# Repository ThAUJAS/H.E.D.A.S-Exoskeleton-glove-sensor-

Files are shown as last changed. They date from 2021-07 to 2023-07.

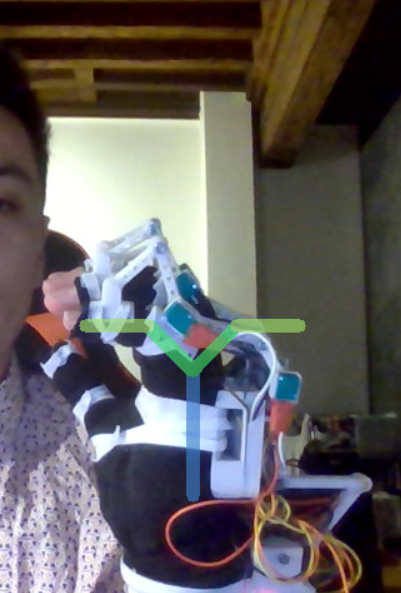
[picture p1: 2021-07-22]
image/45_finger.png

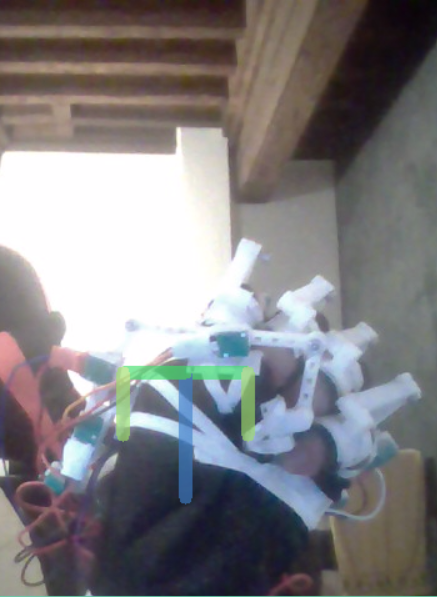
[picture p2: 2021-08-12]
image/90_thumb.png

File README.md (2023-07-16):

# H.E.D.A.S The Exoskeleton glove sensor
This repo is the result of my master thesis for the Staffordshire University. The idea was to create a glove capable of measuring accurately the finger movements (almost every DOF) using cheap sensors (potentiometers). The structure of the glove is fully in 3D parts and assembled with some screws and bolts. The circuit is simple, yet very messy since we have a ton of potentiometers. The values are collected by an Arduino Nano and a multiplexer. Then, I used Unity to simulate a virtual hand, and see if the movements of my hand and the virtual one were corresponsing. 

**The repo is open source, you can Fork and modify as you wish my codes and my design.**

## How to use it
Launch the python script "HEDAS_code" to start the program. A window will open and you will:
- select the port to which the arudino is connected.
- choose whether you want to do another calibration or use a saved one.

The calibration is performed in 5 steps which requires different hand and fingers positions. You can choose to display the camera to help you calibrate. Then, save the calibration under a unique name.

## Requirements
- Tkinter (For the window display)
```
pip install tk
```
- OpenCV (Optional(webcam help for calibration))
```
pip3 install opencv-python
```

## What's included
They are a bunch of files here:
- **HEDAS_code.py** is the Python script. 
- **H.E.D.A.S.ino** is the Arduino code, just compile the file in the Arduino.
- *Sample.json* is the file where the calibrations are saved.

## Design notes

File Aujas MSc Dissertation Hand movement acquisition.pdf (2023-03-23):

ELEC71020 – MSc Project

## Development of a low cost and easy to assemble glove for hand movement acquisition as an open-source project

By Thomas AUJAS

Supervised by Dr Alison Griffiths

A thesis submitted to the Faculty of Computing, Engineering and Science, Staffordshire

University in fulfilment of the requirement for the MSc Robotics and Smart Technologies

MSc Robotics and Smart Technologies

20th of August 2021

School of Creative Arts and Engineering

Staffordshire University

Student number: 20015669

a015669k@student.staffs.ac.uk

## Abstract

Over the past few years, Virtual Reality (VR) has managed to accurately replicate the reality to

immerse the user in a simulated world. One of VR’s best aspect is the interaction with the

environment like grabbing or touching virtual objects. Moreover, many companies developed

gloves to be able to sense hand movements and reproduce them in game for even better

immersion. Therefore, the gloves can be also used for mining, military, transports, and

construction simulators. Sensor gloves are useful in other domains such as medicine. Indeed,

the sensor gloves can be used to measure finger joint angles to control Arthritis (a disabling and

painful disease) easily and with precision. It is also used to control an anthropomorphic robotic

hand and exo-gloves (for rehabilitation purposes) that mimics movements. It could benefit a

wide range of research areas such as in robotics using telemanipulation, or in the medical field

(tissue engineering) for limb regeneration. Finally, it can be used to translate sign language into

a speech or text. The requirements change depending on the application of course, for VR

mainstream games, the accuracy and the number of joints measured by the gloves is low. For

simulations, medicine, accuracy is really important as well as measuring as many joint as

possible. Of course, cost changes depending on the application, whereas for VR games, the cost

must be accessible to the general public, in medicine, the equipment is expensive. Developing

an accessible cost glove while accurately measuring all the hand joints is the goal of the project.

To do so, a 3D printer is involved to print all the necessary parts of the glove. The glove is also

composed of potentiometers that measures the angles. The angles are obtained in different

ways, with a linear relationship or with a second-degree relationship, which requires a

calibration. The calibration helps to have referential position and values, as well as estimating

the polynomial relation between the potentiometers and the joints’ angles. Some testing has

been performed to determine the accuracy and repeatability. The results were acceptable with

a good accuracy overall, but a bad repeatability. The latter could be improved by attaching the

device better to the hand. Another test included a game design software to simulate a hand

model (Unity) was also performed. The hand model moved accordingly to the angles from the

glove values. From the user point of view, the hand is synchronised with its hand, which is

already convenient for VR games.

## Table des matières

4.2 | Arduino code | 37
4.3 | Python | 38
4.3.1 | Receiving the data while interfacing | 38
4.3.2 | Calibration | 40
4.3.3 | Saving the calibration with JSON | 45
4.3.4 | Processing the data | 47
4.4 | Summary | 48
Testing the glove | 49
5.1 | Testing with Unity for a fast visual verification | 49
5.1.1 | Communicating with Python | 49
5.1.2 | Moving the virtual hand | 49
5.1.3 | Visual feedback | 51
5.1.4 | DIP joint issues | 51
5.2 | Accuracy test (and precision test) | 52
5.2.1 | Visual test with an overlay for MCPx, PIP and wristx | 52
5.2.2 | Comparison with an IMU | 53
5.2.3 | MCPz accuracy | 54
5.3 | Repeatability | 55
5.4 | Testing the device on participant’s hand | 56
5.5 | Response time | 56
5.6 | Summary | 56
Conclusion | 57
6.1 | Comparison to objectives | 57
6.2 | Critical appraisal | 57
6.2.1 | Performance | 57
6.2.2 | Calibration | 57
6.2.3 | Electrical components | 58
6.3 | Future work | 58
6.3.1 | Adding the second hand | 58
6.3.2 | Adding a wireless communication | 58
6.3.3 | Adding a haptic feedback | 58
6.3.4 | PCB (Printed circuit board) | 58
References | 59
Appendices | 62
A. GitHub link | 62
B. Unity program | 62

## List of figures

Figure 1: Price range market research results | 9
Figure 2: Spectra Symbol flex sensor 3.75 inches | 10
Figure 3: IMU GY-521 [6] | 11

Figure 5: Flex sensor glove: a) for VR [9], b) for robot hand with additional sensor for the

Figure 6: Rotary sensor glove [11]: a) Kinematics diagram, b) Final design by Ivan Petrov.. 12

Figure 10: Very similar design using IMUs: a) IGES glove [14], b) Salchow-Hömmen’s IMU

Figure 36: Tkinter window, for Hand flat, finger close and thumb far away | 42
Figure 37: Tkinter window, for Hand halfway closed | 43
Figure 38: Tkinter window, for Hand closed | 43
Figure 39: Tkinter window, for Wrist folds at-45° | 44
Figure 40: Tkinter window, for Wrist folds at 45° | 44
Figure 41: Plot of the regression using the Python polyfit function | 45
Figure 42: Tkinter window, asking for the name of the calibration | 46
Figure 43: JSON file storing all the data of calibration | 46
Figure 44: Initial position in simulation | 50
Figure 45: Testing different hand pose in Unity without using the wrist | 51
Figure 46: Test with the overlay at 30° and 60° for both joints | 52
Figure 47: Accuracy test with an IMU connected to a Raspberry Pi | 53
Figure 48: Comparison of measurements of the MPCx from the device and the IMU | 54

Figure 49: MPCz test with major and Index closed, then separated using a 20° 3D printed

spacer | 55
Figure 50: Repeatability test on MCPx | 55

## List of Tables

Table 1: Enumeration of the Degrees Of Freedom of the hand and fingers | 19
Table 2: “Potentiometer” angles collected from the Finger joint angles | 23
Table 3: Glove 3D parts explanations | 28
Table 4: Bill of material for one glove | 36
Table 5: Final organisation of the glove data | 48

## List of Acronyms

Acronym | Meaning | Definition
CAD | Computer Aided Design | Set of software and geometric modelling techniques to design, test virtually - using a computer and digital simulation techniques - and produce manufactured products and the tools to manufacture them.
CMC | Carpometacarpal | Joint where the metacarpal bone of the thumb attaches to the trapezium (carpal) bone of the wrist

DIP | Distal interphalangeal | Joint situated between the proximal bones and the distal phalanges (https://en.wikipedia.org/wiki/Phalanges) of the fingers
DOF | Degrees Of Freedom | The Degrees Of Freedom of a rigid body is defined as the number of independent movements it has.
IMU | Inertial Measurement Unit | Sensor used in navigation, capable of integrating the movements (acceleration and angular speed) to estimate the orientation (roll, pitch and heading angles), its linear speed and its position.
MCP | Metacarpophalangeal | Joint situated between the metacarpal (https://en.wikipedia.org/wiki/Metacarpal) bones and the proximal phalanges (https://en.wikipedia.org/wiki/Phalanges) of the fingers
PCB | Printed Circuit Board | is a support, making it possible to maintain and electrically connect a set of electronic components to one another
PIP | Proximal interphalangeal | Joint situated between the intermediate bones and the proximal phalanges (https://en.wikipedia.org/wiki/Phalanges) of the fingers
VR | Virtual Reality | Computer technology that simulates the physical presence of a user in an environment artificially generated by software

## Introduction

1.1 Aim

Sensor gloves for hand and finger movements acquisition are often very expensive due to the

difficulty required to sense the fingers joints. The price depends on the field in which the glove

will be used. For instance, the gloves used in mainstream Virtual Reality (VR) games only

measure “how much the finger have bent” since accuracy is not their aim, but the time response

is. However, in the field of medicine, all the joints must be measured with accuracy and

precision.

The aim of the project is to develop one sensor glove able to measure the all the angle of the

fingers’ joints with accuracy and precision. It has to be low-cost and accessible for the general

public to be assembled at home requiring only a 3D printer (an open-source project).

1.2 Objectives

- Using Microsoft Forms, writing a questionnaire to start a market research on the project

area. The market research will define what people want/need and in which domain the

glove will contribute the most.

- Literature reviewing some article describing the sensors and the methods to measure the

human hand movements.

- Inspired by the many articles, designing the system with a suitable implementation. Of

course, before testing the whole device, intermediate design ideas must be tested; one

finger, then the thumb and so on.

- Assembling and programming the device, an accuracy and a repeatability test will be

performed.

- Displaying a user interface to simplify the connection and the calibration process.
- Finishing the dissertation with the suggestions for improvements based on the test and

the market research.

- Creating GitHub project to have a link to share the codes (and printing files).
- Writing the dissertation document and preparing the oral presentation.

1.3 Justification of hand acquisition system implementation

Using the results of the market research, a justification for the glove be found. The market

research was a form with multiple question about interest potential users have in this artifact

and why. First, a question asking what such a glove could be used for. The most common

answers were:

- In the industry to manipulate hazardous or contaminated materials.
- For Virtual reality (VR) games or VR training simulation for dangerous operations.
- Replace game controllers and keyboards.
- Rehabilitation of the hand.
- Controlling a surgical robot at distance.
- Motion capture for the film or animation industry.

Nowadays, this type of glove is mostly known to be used for VR games, for motion capture and

for hand rehabilitation [1]-[2]. However, nobody mentioned the use of the sensor glove for a

sign language training system [3]. To know the interest of people in this technology, the

following questions were about the interest in buying a sensor glove. 71 people answered the

questionnaire, 40 would like to buy one. Next, independently from the previous answer, the

question was: “What price ranges would you be willing to pay in pounds? Or which price seems

reasonable?”. The graph bellow shows the result of the question. The chosen ranges are

between 20 to 500 pounds with a peak for 50-100, and there are very few people that are willing

to pay over 500 pounds.

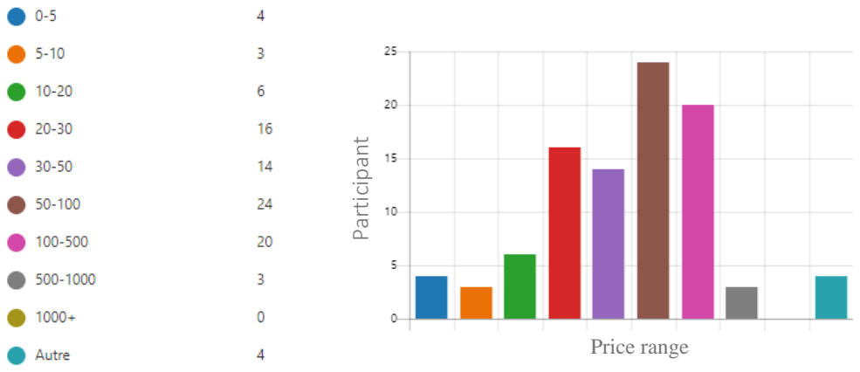
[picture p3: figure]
Price range; Participant

Figure 1: Price range market research results

Concerning the last question, it was asked to give a justification about the price ranges choice.

Most people said that it all depends on the quality of the product (accuracy, speed, precision,

material) and the use of it. For instance, for a domestic use (VR games) a small price is

sufficient, but for a medical use, the price should be higher since the quality should be better.

Many other said that they will not have any personal use for such a glove, which implies that

they do not want to spend too much.

Lastly, since the project is open source, knowing if someone is willing to build the glove is

important. In the questionnaire, it is asked if they had a 3D printer and there is only four people has one at home. Then, the same people were asked if they were interested in printing, buying

the electrical components, and assembling the glove. To this question, three said that they would

try this project.

From the answers given in the market research, it seems that people have an idea of what this

device is capable of. However, less than the half is not interested because they do not see a

personal use. Finally, very few people own a 3D printer and only young people that sees the

potential in VR games are interested in the project. Indeed, the project promises something

inexpensive compared to what in proposed currently, and as seen in the result for the price

ranges, from 100-500 pounds it starts to be expensive.

1.4 Dissertation organisation

The first step for any project to search which sensor suits the most the project. Therefore, the

first section will be about the many glove sensor articles which will be analysed to conclude on

which sensor is appropriate for the project. Then, the dissertation will continue with the design

choices and the system implementation. Next, the glove will be subject to multiple tests and the

results will be discussed in this part. Finally, the dissertation will reach the conclusion, where

a critical appraisal and further works will be discussed.

## Literature review: Methods for hand movement acquisition

2.1 Sensors usually used for hand movement data acquisition

2.1.1 Flex sensor:

The flex sensor is composed of a flexible conductive ink printed on thin flexible base forming

a resistor. The work principle of those sensors is similar to a potentiometer: when they are

folded, their resistances change. The value of the resistance corresponds to “how much the

sensor has been bent”. The unit price for this sensor is between £8-15 [4]-[5] (Figure 1), which

is the highest cost sensor of all.

Figure 2: Spectra Symbol flex sensor 3.75 inches

2.1.2 IMU (Inertial Measurement Unit) (https://www.microstrain.com/inertial/IMU): (https://www.microstrain.com/inertial/IMU)

This sensor measures a body's specific force and angular rate. Therefore, they are composed of

6-axes: a 3-axis accelerometer and 3-axis gyroscope (sometimes 9-axis with a magnetometer).

To build a glove sensor, the values of accelerometer (for orientation) as well as the gyroscope

(for angular speed) are required. The unit price of the IMU is around £0.5 [6] (Figure 3).

Figure 3: IMU GY-521 [6]

2.1.3 Potentiometers

Potentiometers are a three-t (https://en.wikipedia.org/wiki/Terminal_(electronics))erminal (https://en.wikipedia.org/wiki/Terminal_(electronics)) r (https://en.wikipedia.org/wiki/Resistor)esistor (https://en.wikipedia.org/wiki/Resistor) with a sliding or rotating contact that forms an

adjustable voltage divider. Both slider and rotational potentiometer can be used to measure the

joint angles, however, they are used in different ways. For the rotary sensor, the shaft rotates in

the body of the potentiometer, whereas for the slider, the shaft slides inside the body. They are

the cheapest sensor, often sold by group of 10 for less than £3 [7]-[8] (Figure 4).

a | b

Figure 4: Potentiometers a) Rotary [7], b) Slider [8]

2.2 The designs, sensor placement and data acquisition

2.2.1 Virtual Reality acquisition system

The flex sensor is widely known for this type of glove, the sensors were used in the first glove

sensor created for video games: The Power Glove by Nintendo. Therefore, the design is similar

with the sensors glued or stitched to a stretchable glove at each finger from the start to the end

of the finger (Figure 5).

a | b

Figure 5: Flex sensor glove: a) for VR [9], b) for robot hand with additional sensor for the wrist [10]

This type of glove is most likely used for VR because it uses only 5 flex sensors which only

measure how much the fingers have been bent. The rotary potentiometer can also be used to

control the bent angle as well, by 3D printing two links linked by a revolute joint [11] (Figure

6) with:
- the first link fixed to the potentiometer’s shaft and the potentiometer’s body is

embedded to the proximal phalange.

- the second link forms a revolute joint with a part embedded to the distal

phalange.

a | b

Figure 6: Rotary sensor glove [11]: a) Kinematics diagram, b) Final design by Ivan Petrov

2.2.2 Measuring more joints with higher accuracy

Now, if the glove must be used for data analysis with higher accuracy and with more joints

measured, increasing the number of sensors is required. Moreover, they need to be placed in a

different configuration with a specific placement on the hand. For instance, the company 5DT

created the Data Glove ultra 14 in Figure 7 [12] with two sensors for each finger (positioned on

the joints), which allows the glove to measure the joints separately. There are also 4 additional

flex sensors between every finger to detect the fingers movements.

Figure 7: 5DT glove sensor 14 Ultra [12]

Therefore, by applying the same reasoning, adding 2 sensors for each finger to Ivan Petrov’s

glove design improves the number of movements detected by the glove (see Figure 8).

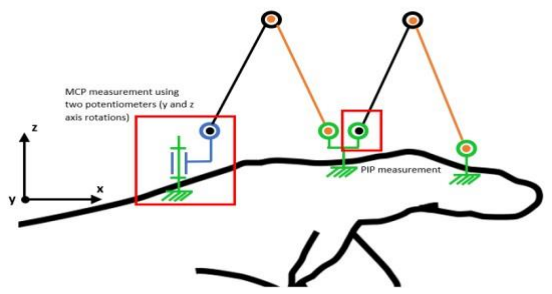
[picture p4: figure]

Figure 8: Modification to Petrov design [11] to measure multiple joints separately

Therefore, by adding more sensor, more joints can be measured, but the glove will be more

expensive of course. Positioning the sensor on the phalanges is the chosen method for the IMU

and the slider potentiometer. An article [13] shows a project that uses slider potentiometers,

springs and flexible wires (fishing lines) to measure only the flexion/extension of the 5 fingers.

The proposed system is showed in Fig. 9 where only one finger is explained for clarity. One

side of the wire is attached to the pole of the slider potentiometer whereas the other end is

attached to the middle of the phalange.

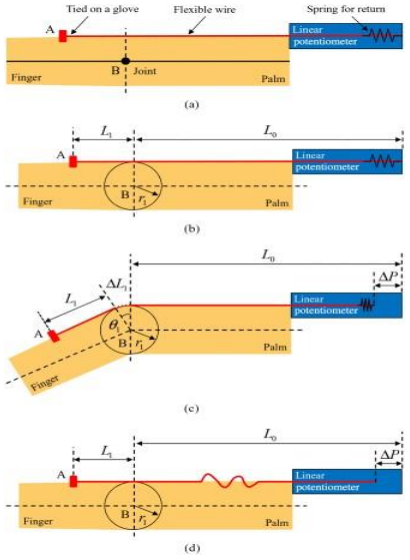
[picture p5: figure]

Figure 9: Slider sensor glove [13]: joint measurement

The angle is computed by measuring the potentiometer value difference which is equivalent to

the value of displacement and knowing the radius of the finger joint which is equal to half the

thickness of the finger, the joint angle is deduced. To compute (or deduce) the angle of the joint,

the sensor displacement of the previous joint must be considered, as the string will pass through

both joints. However, the fingers can move to the right and left but also folding.

Using IMU, measuring all the movement of the joints can be measured more easily. The iSEG-

Glove [14] shown in Fig. 10(a) and the glove developed by Salchow-Hömmen et al [15] in Fig.

10(b) have the same approach: 15 IMUs are positioned on the phalanges of each finger to

measure their orientation and an additional IMU is placed on the palm of the hand to get the

relative orientation and velocity of the phalanges compared to the hand. By measuring the angle

of each IMU and computing the difference in angle between two sensors next to each other, the

orientation of the joints is obtained.

a | b

Figure 10: Very similar design using IMUs: a) IGES glove [14], b) Salchow-Hömmen’s IMU glove [15]

2.3 Data processing

Now that the values are obtained from the sensors, the next step is to process the values. To do

so, a calibration is often used to improve the glove accuracy and define some initial positions.

Furthermore, some sensors require filtering since they are sensitive to noise.

2.3.1 Calibration

A calibration phase must be performed before using the gloves for its purpose. A calibration

routine has been created for every glove to improve the global accuracy of the sensors or simply

make it work properly. The glove wearer must position its fingers in specific poses, with each

pose placing a finger joint group and relevant data glove sensors at their minimum and

maximum boundaries (opened hand and closed hand).

A calibration is necessary if the glove is worn by someone else because the boundaries will be

different. To avoid calibrating every time, a “calibration profile” for each user can be saved.

However, the IMUs require a calibration before usage (by placing the sensor on a levelled

surface) to reduce the errors.

2.3.2 Filtering the noise and signal drift

The data acquired must be treated because many sensors are subject to noise:

- Resistive elements can have signal drift issues.
- IMU’s gyroscope suffers of Angle Random Walk which is a high frequency noise due

to thermoelectrical reactions. Whereas the mechanical noise of the accelerometer sensor comes from thermomechanical noise. Finally, the two IMU’s sensors can have a bias

corresponding to an offset at its output.

By implementing filters before interpreting values, the data can be smoothed and corrected. To

remove the high frequency sensor noise, they must use a low-pass filter, and a high-pass filter

to block low frequency noise. To solve signal drift issues, they removed an estimated error

calculated by getting the average error beforehand.

2.4 Testing methods

Accuracy and Precision (repeatability) tests must be performed to find the performances of the

sensors.

2.5 Accuracy

Measuring the accuracy is difficult because the data from the device must be compared to the

real data. One solution is to compare the sensors between them. The gloves can be compared

with a motion capture device such as the Vicon MX motion. Or the Humanware Humanglove

(UG: Universal Goniometric) with Hall effect sensors, which is one of the most precise glove

sensors for a long time. However, the glove requires a mould of the user’s hand, and it also

requires a tedious amount of calibration. This is the reason this sensor is not consider in the

paper, but it can be used as a reference for testing.

The Salchow-Hömmen et al [15] show the experiment performed in Figure 11: they fixed the

forearm to prevent any disturbance in the motion capture and captured the Vicon and the IMU

glove at the same time. In this experiment, the reference is the motion capture system.

Figure 11: Comparing the IMU and the Vicon system [15]

A similar approach is used for the slider potentiometer [13] in Figure 12. In that case, the IMU

is considered as a reference. The test will consist of folding the fingers multiple times, with the

hand elevated to be able to fold the finger.

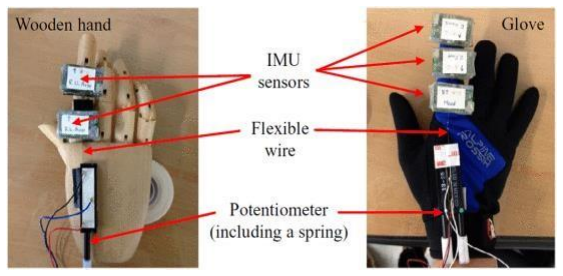
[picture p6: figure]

Figure 12: Testing conditions for slider potentiometers with IMUs [13]

To obtain the best results, the experiment must be performed with multiple devices at the same

time on the same hand. Otherwise, it is really complicated to reproduce the same scenarios or

finger movement for comparison.

2.5.1 Repeatability

Repeatability is the variation in measurements obtained when one person measures the same

unit with the same measuring equipment. For a glove sensor, the values should not shift as the

time goes. Two tests can be performed to control the precision of the glove sensors by [14]:

“The ‘flat hand’ test which examines each data glove’s ability to maintain a minimum

repeatable value after full stretch of each data glove sensor. “and “The ‘plaster mould’ test

examines the ability of each data glove to reproduce angular readings when positioned in a

repeatable position.”.

2.6 Conclusion

To conclude, all the sensors can be used to build a sensor glove, but the goal was to find the

lower cost sensor that can provide an acceptable accuracy and that offers the capability of

measuring all the joints with all their possible movements. The largely used flex sensor is too

expensive to be considered as low cost, exceeding (https://www.linguee.fr/anglais-francais/traduction/exceeding.html) 100£ just for a VR glove whilst being the

easier to implement. The IMU remains the most precise and reliable sensor for any application

(VR or medicine) and the sensors are slightly more expensive than the potentiometers.

Although, it must be calibrated frequently to keep their accuracy and the postprocessing of the

data is more tedious. Finally, the potentiometers are the cheapest sensors, but existing projects

are often protypes and very few tests/ results are provided to conclude on their performances.

Therefore, using potentiometers with Petrov’s method can be the best way to find an

inexpensive solution to complete the objectives and discover the results. Some part of the design

can be similar, though, the calibration and the post-processing should be entirely modified to

fit the aim and the objectives.

## Hand Movement Acquisition: Design and System Implementation

After choosing the potentiometer to measure the hand and finger movements, the design of the

glove will be found. The glove will be composed of many 3D parts develop in a Computer

Aided printed (CAD) software. The part will then be 3D printed and tested. To test, an adequate

program will be developed, as well as the circuitry. Finally, a bill of material containing all the

necessary component to assemble the glove will be established to get the cost of the project.

3.1 Design considerations and technical specifications

The goal is to measure angles the finger joint angle with the lowest cost sensor: the

potentiometers. A potentiometer is a three-t (https://en.wikipedia.org/wiki/Terminal_(electronics))erminal (https://en.wikipedia.org/wiki/Terminal_(electronics)) r (https://en.wikipedia.org/wiki/Resistor)esistor (https://en.wikipedia.org/wiki/Resistor) with a rotating contact that forms

an adjustable voltage divider. The potentiometer’s shaft can rotate around itself in the

potentiometer’s body, therefore, the potentiometer has only one Degree of Freedom. The

Degrees of freedom (DOF) of a rigid body is defined as the number of independent movements

it has.

Each finger has 3 phalanges: proximal, intermediate and the distal phalanx which move with

two joints called proximal inter phalange (PIP) and distal inter phalange (DIP). However,

moving the finger individually is more complex as they move with a freer joint from the hand

called the metacarpal phalange (MCP). The thumb has an additional bone, the Trapezium,

which allows it to move more freely than the others, the joints is called the carpometacarpal

(CMC) joint. The DIP and the PIP are the only joints with one degree of freedom, whereas the

MPC and the CMC have more than one DOF (MPC has 2 DOF and CMC has 3 DOF). All the

joints and phalanges are represented in Figure 13.

Figure 13: Joints and phalanges of the hand

Due to the small area that represents the hand and the fingers, measuring accurately the hand

movement becomes a real challenge. And unfortunately, that makes the devices often very

expensive for the general public. The potentiometers can measure only one degree of freedom,

so a clever design to sense movements on multiple axis must be found. There is a potentiometer

for every DOF in the hand:

Table 1: Enumeration of the Degrees Of Freedom of the hand and fingers

The total number of DOF for the fingers is 22, and 25 with the wrist, which is enormous. The

objective would be to reduce the number of potentiometers used to reduce the cost and the

weight of the device to be more comfortable for the user. Hrabia et al [16] conducted an

experiment to find a relationship between the DIP and the PIP. The movement of the distal

phalange is indeed related on the movement of the intermediate because the two are moved by

the same muscle. Therefore, after experimenting and multiple people and by using a normal

distribution to verify the results, they found an approximated equation relating the two joints

for every finger (except the thumb):

∡DIP = 0.88∡PIP for all four fingers (with SD=0.10, R2=0.77)

From this estimation, the DIP is ignored which reduce the number measurements on the four fingers. Another joint where a DOF that can be ignored is the CMC of the thumb. The CMC, with 3 DOF, allows the thumb to perform a wide variety of movements.

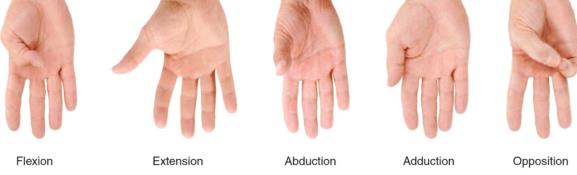
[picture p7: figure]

Figure 14: Movements of the thumb [17]

Joints | DOF Location | Total DOF
DIP | 1 | Every finger | 5*1 = 5
PIP | 1 | Every finger except the thumb | 4*1 = 4
MCP | 2 | Every finger | 5*2 = 10
Wrist | 2 | Only the wrist | 2
CMC | 3 | Only the thumb | 1*3 = 3

This will be the most tricky and difficult joint to measure. Therefore, a relation between the

CMC and MPC of the thumb concerning the abduction and adduction is found. The movement

of the CMC and MPC on the right and left are performed on the z axis, as shown in the Figure

15. The following relationship has been tested in the Part 5.1 of this paper:
∡CMCz | = | 2
3

⁄ ∡MPCz

Finally, concerning the wrist, even though the hand has 3 DOF compared to the arm, the wrist

can be reduced to 2 DOF. Indeed, from the arm the hand can rotate around 3 different axes, but

the wrist offers only 2 rotations. The last rotation is operated by the arm which rotates around

itself. Therefore, this rotation is ignored for our actuation system. Therefore, the total number

of DOF that can be measured is reduced to 19 DOF.

Lastly, the potentiometers are not the smallest (10x11x22 cm) but looking at the size of the

fingers, the size of these potentiometers will not be causing problems. However, it is important

to remind that the aim is to have a comfortable glove for a long use and adaptable to every size

of hand.

Electronically speaking, the Arduino Nano is the microcontroller used to collect the data from

the potentiometers because of its small size. However, as mentioned before, the Arduino must

read 19 potentiometers and there are only 8 analogue pins available on the Arduino. Therefore,

the use of a multiplexer is required, which is an electric component with 16 analogue

inputs/outputs. The multiplexer pins can be read separately by sending a binary number

indicating which pin to read. Finally, the data will be collected by the Arduino and send to the

computer.

3.2 Mechanical design (kinematic diagram)

3.2.1 Kinetic diagram

A kinematic diagram is a drawing of the joints which connect the links together. It is used to

help to understand how a mechanical system moves. Previously in part 3.1, the terminology

“number of DOF” was used, but for the kinematic diagram, it is better to use mechanical joint.

A joint -or mechanical joint- is a section of a machine that connects two a link/part to another,

the name of the joint depends on the number of Degree of Freedom it provides. For instance,

the potentiometer has one DOF, it is therefore called considered as a Revolute joint. The MPC

and wrist have 2 DOF which represent a Universal joint. The CMC has 3 DOF which

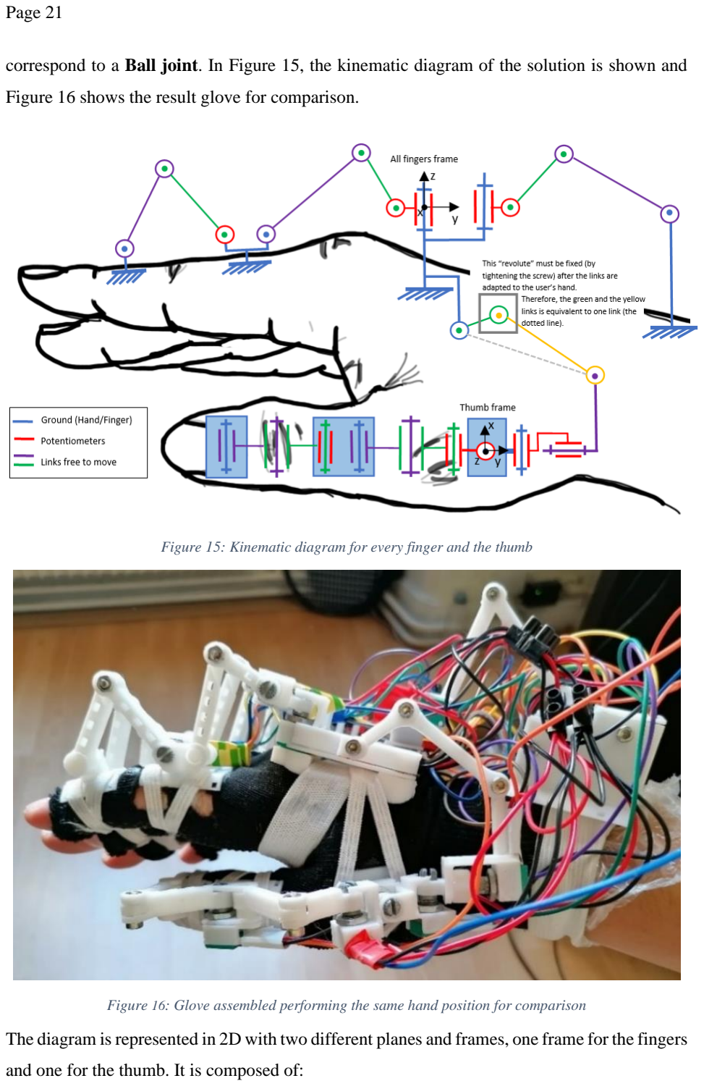
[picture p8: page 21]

correspond to a Ball joint. In Figure 15, the kinematic diagram of the solution is shown and

Figure 16 shows the result glove for comparison.

Figure 15: Kinematic diagram for every finger and the thumb

Figure 16: Glove assembled performing the same hand position for comparison

The diagram is represented in 2D with two different planes and frames, one frame for the fingers

and one for the thumb. It is composed of:

- mechanical joints: In our case, the drawing is exclusively composed of revolute, that

can be represented as a circle or by a cylinder trapped between two lines (because a

revolute joint can only rotate around the axis).

- the body or ground: the ground is the part of a system that does not move, it is fixed.

In our case the grounds are the hand and the fingers (the phalanges in particular).

- links: they are straight lines that link two joints together.

3.2.2 Link movements and angles relations

As stated in the Design considerations, the device’s sensor for the fingers’ joints are

potentiometers which implies that only revolute joints can be utilize. Since the DIP and PIP

joints are revolute, in theory, the measurement of these joint should be easier. In reality, to

measure the angle between two phalanges, the potentiometer’s axis should be situated at the

same location where the finger folds. Unfortunately, this solution is possible only on the side

of the finger, which is only possible for the index and the pinkie. The only location where the

movement of the user will not be contained is on the top of the phalanges. In addition, the glove

must be comfortable and adaptable to every hand size. After testing multiple design and

solutions, a similar design to Ivan Petrov’s work has been found (at least for the joints in the x

axis). Therefore, the final chosen design should have been exploitable. However, in the article,

he measured the bend of the fingers by calibrating a start and end position, whereas the goal of

the project is to measure the finger joints’ angle values. From this design, two types of relation

between the angles of the joints and the sensor values can be found:

- The linear relations: The value obtained by the potentiometer will be the angle at which

the joint moved, which is basically an equality. This happens only when the potentiometer

is the only revolute rotating around an axis. From the Figure 15, only the MCP in the z axis

(reduced to MCPz), the CMC in the x and y axis (reduced to CMCx and CMCy respectively)

and wrist in the z axis (called wristz) are in this case.

- The second-degree relations: to measure the PIP and MCPx, wristx and CMCx which all

rotate around x in their frame, adding a revolute joint was necessary. Indeed, unlike the

MCPz, the when the finger folds, the link will hit the finger. Moreover, the distance between

two phalanges will change as the finger folds.

The final design is two revolute joints fixed the phalanges near to the joint. One of the

phalanges’ revolute is a potentiometer with a link attached to it. Another link is connected to

the previous link and to the phalanges as shown in Figure 15. Since there are two revolute joints moving together, a linear relationship does not exist anymore. Instead, there is a polynomial

relation, a second degree in particular. This assumption can be verified using Fusion 360 by

simulating the joints and links attached to the finger as shown in Figure 17.

Thanks to the simulation, by changing the driving dimension, the finger folding is

simulated. The potentiometer values can be collected with a driven dimension in

FUSION 360. By bending the finger at different angles and by collecting the values

obtained by the “potentiometer”, a table comparing the two values has been created in

Table 2. Of course, this is just a simulation, in reality, the data obtained from the

potentiometer is between 0 and 1023.

Table 2: “Potentiometer” angles collected from the Finger joint angles

The table values are used to plot a scatter plot in Excel. From the scatter plot, an option

to estimate an equation of that would go through every point is proposed, this is called

a regression. The choice concerning the type of regression is wide: linear, polynomial,

exponential, logarithm and so on. The best result was obtained with the polynomial

regression with a degree 2, as shown in the Figure 18.

Figure 17: Simulation of the PIP joint with the two links in blue

Finger joint angles | 190 | 180 | 170 | 160 | 150 | 140 | 130 | 120 | 110 | 100 | 90 | 80
Potentiometer angle | 64.9 | 60 | 55.2 | 50.4 | 45.8 | 41.5 | 37.3 | 33.4 | 29.9 | 26.6 | 23.6 | 20.9

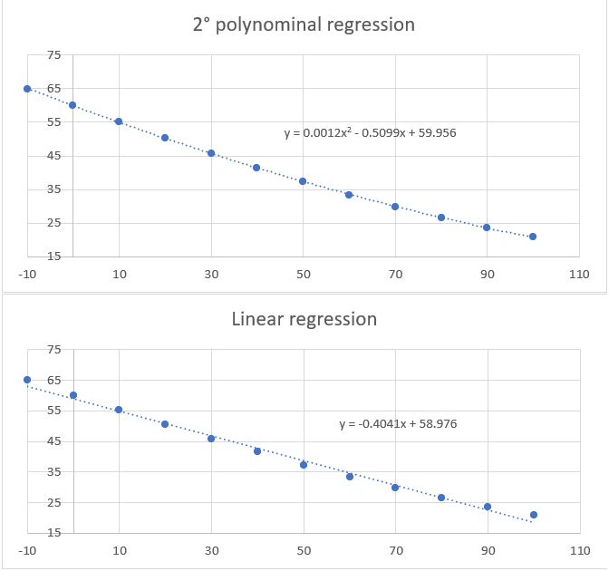
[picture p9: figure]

Figure 18: Fitted curves for the finger vs potentiometer

3.2.3 Alternative design

There was one possible design to keep a real linear relationship using another 1 DOF

mechanical joint widely used in robotic: the prismatic joint. Compared to the revolute, the

prismatic slides without rotating, whereas the revolute rotates without sliding, but both move

around one axis. The prismatic was useful to create a linear movement in one direction.

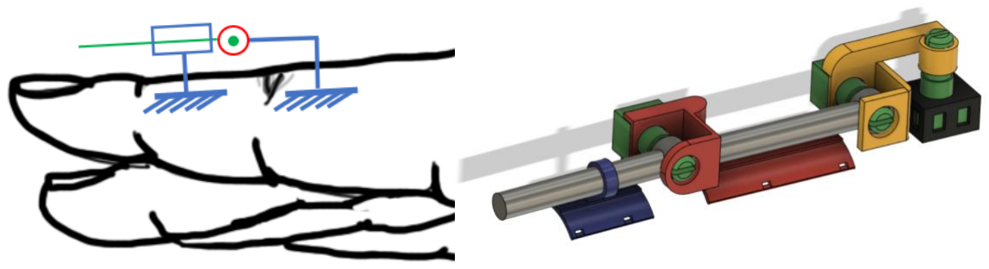
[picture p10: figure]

Figure 19: Kinematic diagram and design of an alternative solution

However, after testing the solution in Figure 19, the parts were moving too much on the finger

and the design would not fit the finger nor fit every hand size.

3.3 Electronic requirements

Now that the measurement design has been decided, the circuit diagram must be drawn before

wiring anything. Once the circuit is ready, wiring the components together is easy, and before

powering the system, a verification of the circuit must be done.

3.3.1 Circuit diagram

Figure 20: Circuit diagram of the glove

The diagram looks messy, but at least in theory, the circuit is simple. Indeed, every electric

component in this circuit are powered to the Arduino in parallel. It implies that every

component will be supplied with the same voltage, but the current is variable. Therefore, the

current passing through the variable resistances can be measured as:

U = RI ↔ I =

U
R

with U the tension/voltage in Volts, R the resistance in Ohms and I the intensity/current in

Amper.

The current is measured using the analogue pins of the Arduino that can read numerical data or

with the Multiplexer which has the same purpose.

3.3.2 Power consumption

The circuit diagram is finished, however, before wiring, the power consumption must be found

to ensure that the Arduino can supply all the components. Every component in the circuit is in

parallel that means that all the components are supply with a tension of 5V. However, the

current drawn by the components must be determined. The components that draw current are:

- 19 potentiometers:

The potentiometers’ resistance is R1 pot = 10 kΩ, since there are 19 potentiometers:

I19 pot = n × I = n ×

U
R

= 19 ×

5
10000 = 0.0095A = 9. 5mA
- Multiplexer: The 74HC4067 is a CMOS logic chip which contains CMOS

logic. Having a very low static current is a property of this kind of logic (inputs fixed at

one or zero) as shown in the see datasheet [18], page 4: Icc < 160 µA

IMUX = 160 µA

From the current draw by every component, the total current of the circuit can be deducted:

ITot = I19 pot + IMUX + 9.5mA + 160 uA = 10. 16 mA

And the power consumption:

P = ITot × 1 hour = 0.01016A × 3600s = 36. 576A. h

The current provided by the Arduino pin 5V/Ground when powered through USB is

approximately 400mA (according to the documentation of the Arduino nano), whilst all the

components consume only 10.16mA, which represent only 2 percent. Therefore, the Arduino

will largely be able to power all the components. Furthermore, if the device would have been

wireless and supplied by a battery, 35.576 A. h would a small consumption.

3.3.3 Connection within the assembly

All the potentiometers’ terminals are wired before assembling, but the pins of the Arduino or

the multiplexer are not connected yet. The assembling does not required soldering, although it

is recommended; indeed, the wires are Dupont connecters (Jumpers wires). However, with the

small size of the potentiometer, the terminal pins are very small, and the wires have not a good

connection. Therefore, their plastic housings are removed and to fix the wire to the terminals,

the head of the wire is crimped to the potentiometer’s terminal. To avoid shortening the circuit,

electrical tape separates the wires. The other head of the wire still has the housing because they

will connect to the Arduino and multiplexer which have standard pins. Once all the

potentiometers are fixed to the glove, the data terminals of the potentiometers can be wired to

the Arduino and Mux. Moreover, the alimentation terminals can be attached together using

small terminal strips, joining at some point the 5V and GND pins on the Arduino as shown in

Figure 26. Of course, solder the pins and the wires is the best solution to ensure a more reliable

connection, but this requires a good experience in soldering. Furthermore, some components

such as the multiplexer and the IMU cannot be bought with the pins soldered. It was not

particularly difficult to solder the pins, but for the rest of the project, continuing without

soldering was important. Indeed, since the project is open source, it should have multiple

options depending on the person’s equipment. With some research, and depending on the

country, those parts can be bought on other sites with the pins soldered for a reasonable price.

3.4 Software requirements

To realise this artifact, three software were required: Arduino to collect the data, Python to

process the data and design an interface, and finally Unity to display a simulation of a hand

replication see Part 5.1Testing with Unity . However, since Unity is a cross-platform (https://en.wikipedia.org/wiki/Cross-platform) game

engine, (https://en.wikipedia.org/wiki/Game_engine) a game can be build and run as an application .exe. Therefore, except if the user wants

to modify or create a game from Unity, Unity should not be required. Arduino and Python are

required to the good functioning of the glove. Moreover, Python needs some libraries that are

not initially installed, this is the list of libraries:

- Tkinter: used to show a window with interactive widgets such as button, entries, and

images.

- Socket: used to communicate between two devices wirelessly or between two languages

(C# and Python for instance)

- NumPy: a well-known library with many mathematics functions such as polyfit which

will be used to perform polynomial regressions.

- OpenCV: library specialised in real-time image processing.

3.5 3D printed Glove

The objective of the 3D modelling process was to facilitate the assembly as much possible. The

glove is entirely composed of 3D printed parts attached with strip band, with or it can be sewed.

Basically, the goal is to print the parts, remove the eventual supports and assembling it without

any post processing.

3.5.1 The different parts

The 3D models were generated with the educational version of Fusion 360, a Computer Aided

Design (CAD) software. All the parts presented here will be 3D printed, and some parts such

as the potentiometers are here to visualise better how the system works. All the potentiometers

are fixed to the part using the nut provided with them. The following Table 3 explains all the

different parts of the glove.

Table 3: Glove 3D parts explanations

| This part holds the potentiometer that is measuring the angles of the MPC on the X-axis. The circular shape with the bar in the middle is attached to the potentiometer that measures MCP on the Z-axis.
a b c | Those links attached to the potentiometers on one side and to the other phalange on the other. They are be assembled using a screw and a nut, slightly tighten to allow the rotation. a. links are attached to the MCPx potentiometer b. links are attached to the PIP potentiometer c. links are attached to the wristx potentiometer
| With its semi-cylindrical shape, this part is fixed to the proximal phalange. There are holes so that it can be sewed to the glove. Or it can be glued on the glove. The upper section of this part holds the potentiometer that will measure the angles of the PIP. The shaft near the potentiometer is here to attach the links above.

With its semi-cylindrical shape, this part will be fixed to the

proximal phalange. There are holes so that it can be sewed

to the glove. Or it can be glued on the glove.

The second part of the links (without the bar in the middle)

will be attached to the pin. To embed the pin, it needs to be

forced into the hole.

The main body of the device is this part. It is separated in

three parts:

1. The first part is the cover which is screwed to the

other pieces using screws and nuts. There are holes

with hexagonal shapes to embed the nuts. Moreover,

there are two screw holes’ size on the middle of the

cover to attach the potentiometer’s holder of the

wristz. Lastly, a huge hole is here to let the wires

through.

2. The second part holds the potentiometers’ holders of

the MCPz. There are four of them for each finger.

For the thumb, on the left of the cover, a screw hole

is here to attach the CMC parts.

3. The last part must be attached to the hand which

explains its round shape. A rounded extrusions is

present in the centre of the part to allow an elastic

strap to be stuck into.

This is the box which contains the electronic components: the Arduino and the multiplexer. The parts on top are for the Multiplexer, the wires need to be connected, then the lid can be screwed, and the wires are trapped within the box. The part on the bottom is for the Arduino but the Multiplexer’s box as well. The Multiplexer box is fixed to the bigger box and the Arduino fits in the back. The lids (middle) have a bigger hole to allow the wires to go in the slot.

The parts of for the CMC joint are similar to the others but with some modifications. • The black part is attached to the thumb metacarpal phalange. • The links are meant to be one, since the joint in the middle is supposed to be an embedded joint (0 DOF). To do so, the screw and the nut should be tightened as much as possible. The aim of this joint is the possibility to adapt to the user hand. • The CMCy (blue and white part) is the only part measuring on the y axis, thus the part is different from the others.

3.5.2 The assembly

The assembly consists in assembly every parts together. The assembly is composed of 4 sub-

assembly:

1. The MCPx, MCPz and PIP sub-assembly for all fingers (Figure 21). The thumb also has the

same parts but reversed and the MCPz has a modification. This is the first prototype of the

whole glove because it can measure one finger already. Therefore, once this assembly have

been validated by testing with Unity (see part 5.1), the glove has been designed around the

same concept:

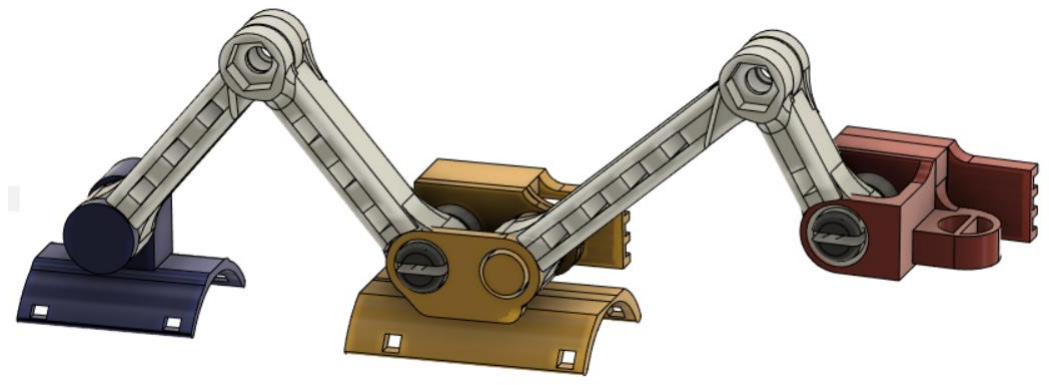
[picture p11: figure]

Figure 21: MCPx, MCPz and PIP sub-assembly for all fingers

2. The CMCx and CMCy for the thumb movements (Figure 22):

Figure 22: CMCx and CMCy for the thumb movements

3. The Arduino and multiplexer box. The pin that holds the link can be printed with the

multiplexer box or it can be glued to the box afterwards (Figure 23):

Figure 23: Arduino and multiplexer box

4. The body of the glove, where all the previous sub assembly are connected to (Figure 24):

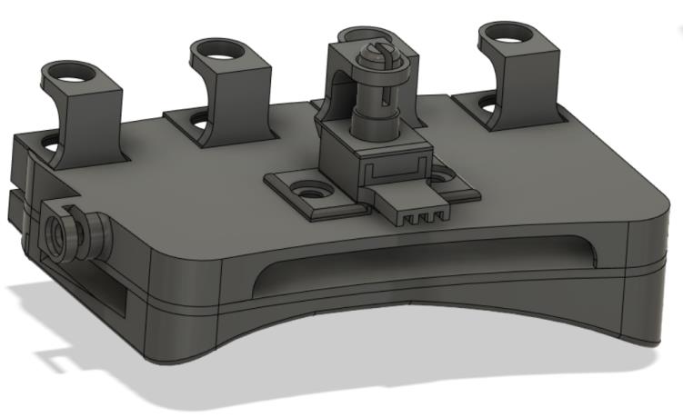
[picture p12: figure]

Figure 24: Assembly where all the finger parts are connected to

Finally, the assembly (Figure 25) without the fabric glove should look like this (the PIP and

MCP parts are normally reversed):

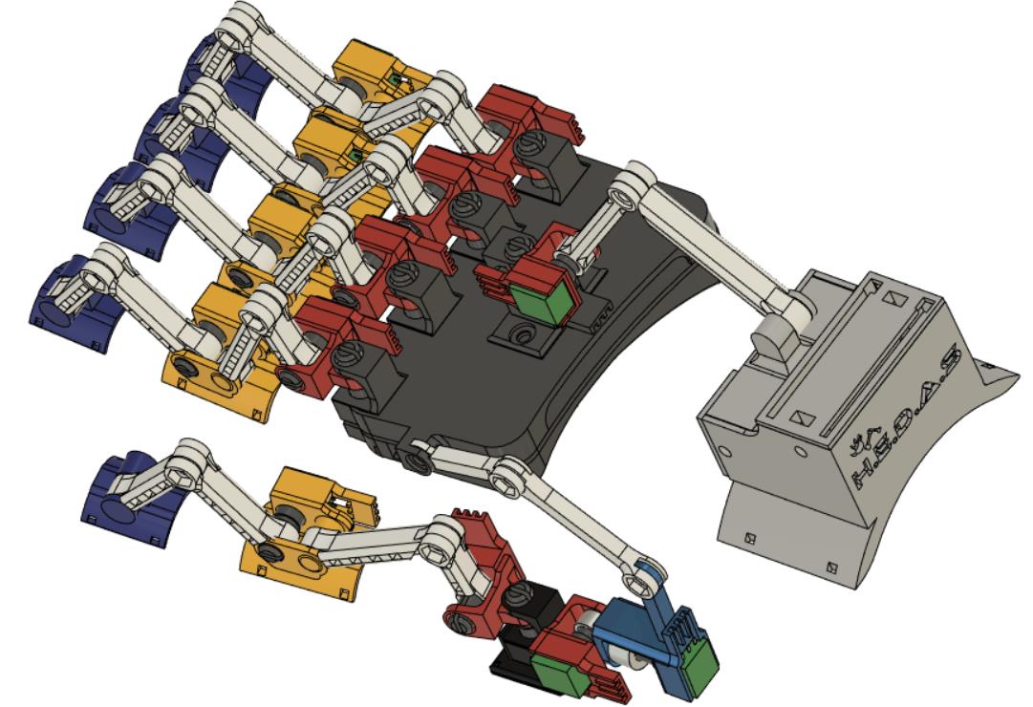
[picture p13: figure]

Figure 25: Complete assembly in the CAD software

The picture bellow is the real glove assembled on the fabric glove using glue and elastic bands.

The parts can also be fixed to the glove by sewing them (notice the holes in every part attached

to the glove). However, the glove is to elastic therefore, the sewing method is not appropriate.

With a stiffer glove, this method could work:

Figure 26: Picture of the glove fully assembled

3.5.3 The printer and the settings

The printer used to print all the part was the Creality Ender 3, a low-cost printer with an

acceptable accuracy. The software used to slice the 3D files is Ultimaker Cura. This software

is called a slicer because it will divide the part in layers. The software offers a variety of options

to enhance the printing experience such as the layer height, wall thickness, support and so on…

All the part can be printed with a layer height of 0.28 (the lowest resolution) which is sufficient

but the circular part of the potentiometers' holder containing the links can break more easily

since they are very slim. However, it is not important since a small area stopping the link from

moving is required. Even if the parts are relatively small, the printing time was quite long,

therefore, printing with a high layer, lowers the printing time. But the prints often lose accuracy

and their strength in some area as well. The parts were printed with a PLA filament, they had a

great strength despite the thin shell. Of course, the parts could have been printed in another

material with a higher yield strength such as ABS or PETG, but they are often more difficult to

print. The potentiometers' nuts were tightened directly on the part, and the parts never broke.

Furthermore, when the finger folds, the links are subjected to some forces, but they are strong

and never broke.

The printing can be divided in 4 parts. The following screenshot are from the Cura, and they

show the different sub-assembly printed together:

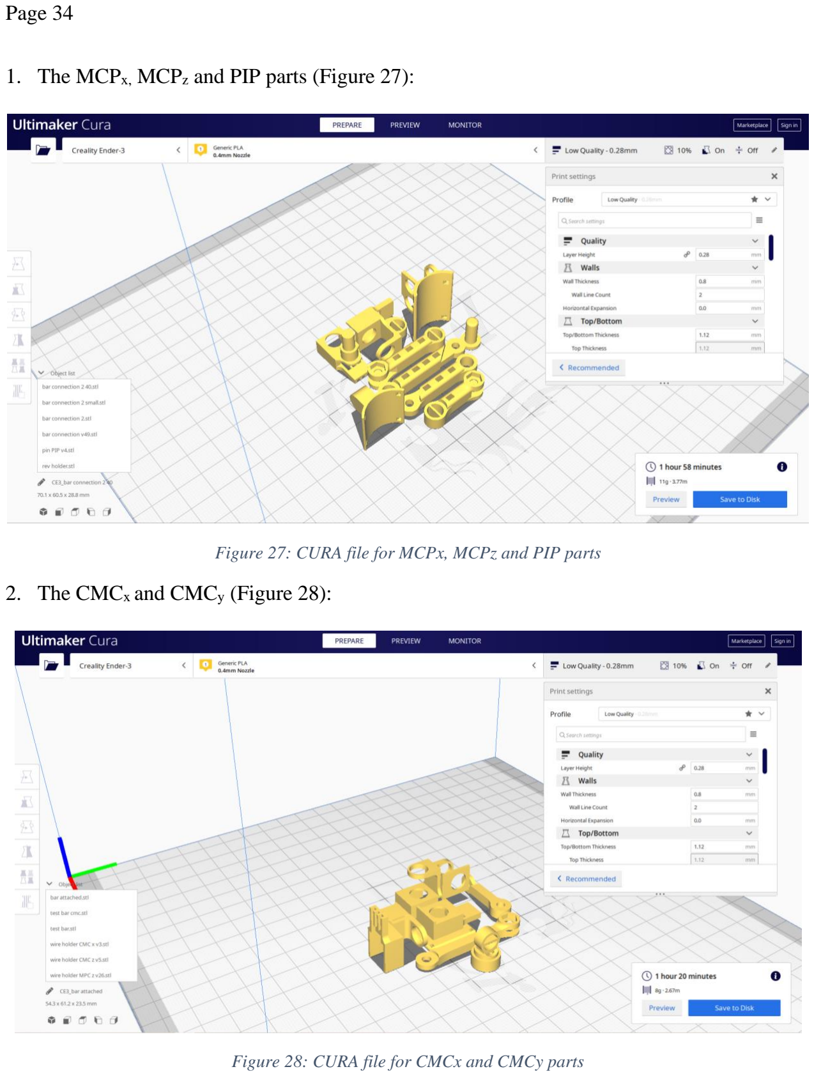
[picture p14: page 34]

1. The MCPx, MCPz and PIP parts (Figure 27):

Figure 27: CURA file for MCPx, MCPz and PIP parts

2. The CMCx and CMCy (Figure 28):

Figure 28: CURA file for CMCx and CMCy parts

3. The box for the Arduino and the multiplexer and the links for the wrists (Figure 29):

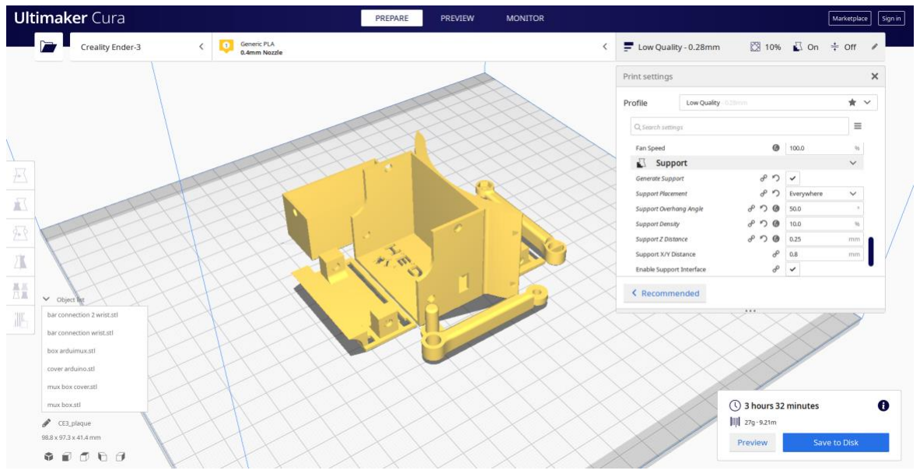
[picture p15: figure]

Figure 29: CURA file for the Arduino and the multiplexer boxes

4. The body/hand bracelet:

Figure 30: CURA file for the hand bracelet

Then, the parts sliced are simply stored in a SD card and then, the SD card is plugged into the

3D printer. The file containing the .gcode of the print can be chosen and the print starts. By

summing all the duration of printing, the time for printing the glove can be determined. The

time to print all the parts necessary to assemble the glove is 17h and 56 min.

3.6 Cost (bill of materials)

The Table 4 is a bill of material where all the parts required for this artifact, as well as their

prices and the links to the shop are included.

Table 4: Bill of material for one glove

All the component for this glove can be found on the website Aliexpress for a reasonable price

of 20€ or £17,20. Concerning the 3D printer, since it is required to own one to build the glove,

it will be not counted as a cost. However, the plastic filament is a consumable, so it is

considered. First, the amount of filament must be determined:

- MCPx and PIP parts: 5x11 = 55g
- Arduino and Multiplexer box/bracelet: 24g
- CMC parts: 8g
- Hand bracelet (body): 36g

In total, the filament used is 130g. Depending on the type of filament and the brand, the cost

varies. The filament used for the device presented in this artifact costs 20 pounds for 1kg. Therefore, the cost of the filament consumed is 123
1000

× 20 = £2.46.

The cost of one glove is estimated to about 23,20€ or £19.66. From the market research, people

were considering £50-100 as a reasonable price range, therefore, the aim to develop a low-cost

sensor is a success.

Part | Price (€) | Link | Product descriptions
19 rotary potentiometers | 3.98 | Aliexpress (https://fr.aliexpress.com/item/33011428749.html?spm=a2g0o.cart.0.0.18443c00iMQmSW&mp=1) | 2x10 rotary potentiometers
Arduino Nano | 3.9 | Aliexpress (https://fr.aliexpress.com/item/4000587268145.html) | One Arduino nano + 30cm cable
Multiplexer 16 Pins | 1.4 | Aliexpress (https://fr.aliexpress.com/item/32787406285.html?spm=a2g0o.cart.0.0.651a3c00y2Xxtl&mp=1) | One multiplexer (no pin soldered)
IMU (GY-521) | 1.9 | Aliexpress (https://fr.aliexpress.com/item/32648074007.html) | One IMU (no pin soldered)
Jumpers F to F of 20/30 cm | 3.87 | Aliexpress (https://fr.aliexpress.com/item/32898199540.html?spm=a2g0o.cart.0.0.651a3c00y2Xxtl&mp=1) | 40 Female to Female Jumper of 20/30 cm
Wire-nut connector | 0.65 | Aliexpress (https://fr.aliexpress.com/item/32936640163.html?spm=a2g0o.cart.0.0.651a3c00y2Xxtl&mp=1) | 12 pieces of Wire-nut connector
Mini USB cable of 1.5m or 3m | 3.90 | Aliexpress (https://fr.aliexpress.com/item/32870987678.html) | Mini USB cable of 1.5m or 3m
Elastics | 1.21 | Aliexpress (https://fr.aliexpress.com/item/4001123233641.html?spm=a2g0o.cart.0.0.651a3c00y2Xxtl&mp=1) | Elastic band: 3mm large and 5m long
Nut + Screw m3x8: 23 pieces | 2.26 | Aliexpress (https://fr.aliexpress.com/item/10000150053486.html?mp=1) | 3x10 screw M3x8 and 25 M3 nuts
Total | 20 €

3.7 Summary

Overall, the design has been chosen to be easy to assemble once the parts are 3D printed.

However, the values obtained from some potentiometers needs a calibration and post-

processing. Furthermore, the wiring, simple in theory, is much more complicated in reality, and

it requires to be vigilant. In return, the glove is very cheap, and it cost less than 20 pounds.

## Coding

The programming is divided in 3 parts:

- The Arduino code: the role of the Arduino program is to send the data thought the

Serial port.

- The python code: Python can read the data send by Arduino. Python is used to display

an interface that the user will use to select the serial port and the calibration process.

- Unity code (in C#): the code in Unity is in C sharp, the goal of Unity is to move the

hand and finger when it receive data from Python using “socket” to quickly test the

device.

In this section, only the Arduino and Python code will be treated because Unity is used to test.

Therefore, the following discussing will be about collecting data and processing it.

4.1 Languages and software justification

Using python was necessary to display an interface to facilitate the calibration process with

images, explanation, and interactive buttons. Moreover, Python can be used to write and to read

files, or to connect a Bluetooth device easily, and overall, Python is compatible with most

software and application. Lastly, for further work, Python is the ideal coding language used for

machine learning, NLP, and neural network connections. Unfortunately, coding an Arduino

with Python is not possible. Instead, the Arduino library Nanpy allows a Python code to send

command to the Arduino, for instance reading an analogue value or toggling a digital pin.

However, this method is not ideal since sending the command and waiting for the values is time

consuming. Therefore, instead of sending command with Nanpy, the Arduino is sending the

value to the computer through the serial port (USB) and received by Python to be processed.

4.2 Arduino code

The Arduino code’s role in the software part is the reader and sender of the value to the

computer through a Serial communication. The following flowchart in Figure 31 shows the

code operation.

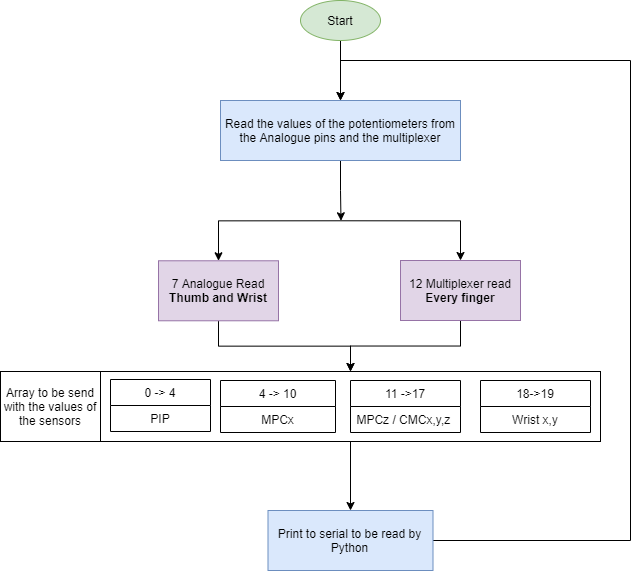
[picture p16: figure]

Figure 31: Flowchart of the Arduino code

The data are simply collected one by one in a specific order to simplify the process in Python.

Once the data is collected, it organised the data in a specific order and then it is transmitted to

Python through the Serial port. To do so, the values are printed in the serial port with

Serial.print and they are separated by a comma. The Arduino code is stored in the Arduino,

therefore, as soon as the controller is powered, it starts printing the data. The data is sent but

not yet received by Python.

4.3 Python

Once the data is sent by the Arduino, Python must read the Serial Port in order to receive the

data. A calibration must be performed before using the glove, but the user also has the choice

to use a previous calibration.

4.3.1 Receiving the data while interfacing

It is important to know to which port the Arduino is connected. With the help of the library

serial.tools.list_ports, every port (USB, Bluetooth…) used by the computer can be listed. The

user is then required to select the good port. The port can be determined when compiling the

Arduino code, the user have to choose which port to use to compile. Once the serial port is

chosen the data be read through the serial port.

Figure 32: Arduino software indicating the Serial port

If a device is connected, the message “Choose the part to which the device is connected”

followed by the list of port is displayed on the screen as shown in the first picture of Figure 33.

Otherwise, this message will show up as shown in the picture bellow.

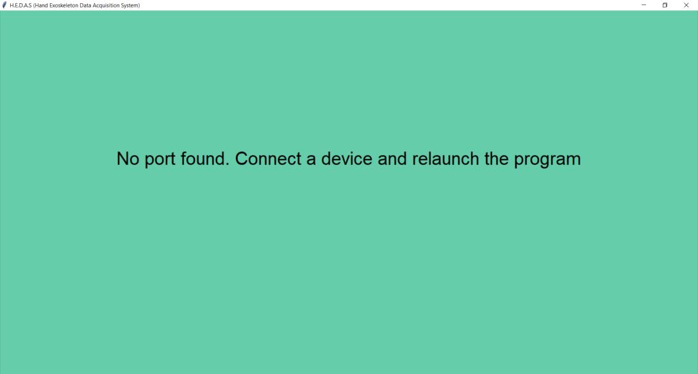
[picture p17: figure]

Figure 33: First pages asking for the Serial port

The windows show in Figure 33 are opened when the Python code is launched. They are created

with the library “Tkinter”. Tkinter allows to open a window with text, button, entries, and it is

compatible with OpenCV. The button is linked to a function; therefore, each function

corresponds to a specific action.

Once the Serial port is chosen, the data should be received to calibrate afterwards. However,

the interface runs in its specific loop, and the code is paused as long as there is no action.

Therefore, while the interface is waiting, the code is stopped, and the data cannot be received

from the Arduino. To rectify this issue while keeping the code in one file, the use of Threads is

required. Python threads are used to launch multiple lightweight processes (tasks, function

calls) at the same time but that doesn't necessarily mean on multiple processors. Python threads

will therefore not speed up a program that already uses 100% of a CPU's time which is different

from parallel programming.

In total, three threads will run in the code:

- displaying the interface while waiting for an input (pushing buttons or entering values)
- collecting the data from the Arduino and processing it, and finally, sending it. Of course,

the data is not processed nor send until the calibration is done.

- showing the webcam feedback of the computer to help calibrating the glove (see next

part “Calibration”)

4.3.2 Calibration

The calibration is an important part of the process. As seen in the part 3.2 Mechanical design

(kinematic diagram), since there is a second-degree relation between the angle joint of the finger

and the potentiometer, multiple measurement must be done to perform a polynomial regression.

Moreover, even if the relation between the fingers’ angle and the potentiometers is linear, a

measurement at a known angle is taken to obtain the “Zero position”.

In part 3.2, there was a measure every 10 degrees to calibrate the glove, which is not

considerable for the user since this is time consuming and tiring for the hand. The goal is to

reduce the number of measurement while keeping the same accuracy. By measuring 3 values,

evenly distributed, the fitted curves have similar equations. The Figure 34 shows the polynomial

regression for with only 3 measurements in comparison to 11 measurements.

Figure 34: Comparison between polynomial regression with 11 and 3 values

Therefore, to calibrate the MCPx, PIP and the wrist, only 3 measurements will be taken at the

angles:

- 0, 45 and 90 for MCPx and the PIP joints since they can reach those angles
- -45, 0 and 45 for the wrist joint since it can only reach those angles.

However, the user does not know when it reaches those angles. Therefore, the interface is here

to help. In the following Figures, the interface shows how the hand should be positioned to have

the correct angles. Furthermore, there is a possibility to open the webcam and to show the video

feedback with an overlay using OpenCV. The overlay displays three lines representing different

parts: the hand and/or the phalanges or the arm. The user can superpose its hand on the lines to

replicate the same joint angles. In Figure 35. On the left, the picture shows the position to

replicate. On the right, there is the possibility to activate the webcam that shows the video with

the overlay. Once the button pressed, the webcam feedback will show up with the overlay as

shown in the following pictures.

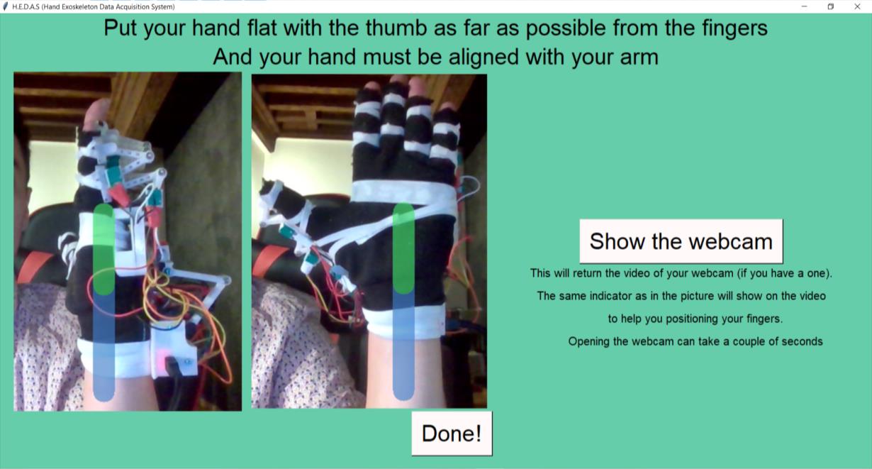
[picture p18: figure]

Figure 35: First step of calibration with possibility of showing webcam

The following figures (Figure 37, Figure 36,Figure 38Figure 39Figure 40) are the step to

calibrate, with the webcam feedback and the glove positioned behind the instructions. Once the

hand is in correctly positioned, the button “Done!” can be pressed and the values are saved, and

the next window will appear with new instructions.

1. Values measured for the calibration: Initial MCPz, initial CMCx,y, 0° MCPx, 0° PIP, 0°

wristx (Figure 36)

Figure 36: Tkinter window, for Hand flat, finger close and thumb far away.

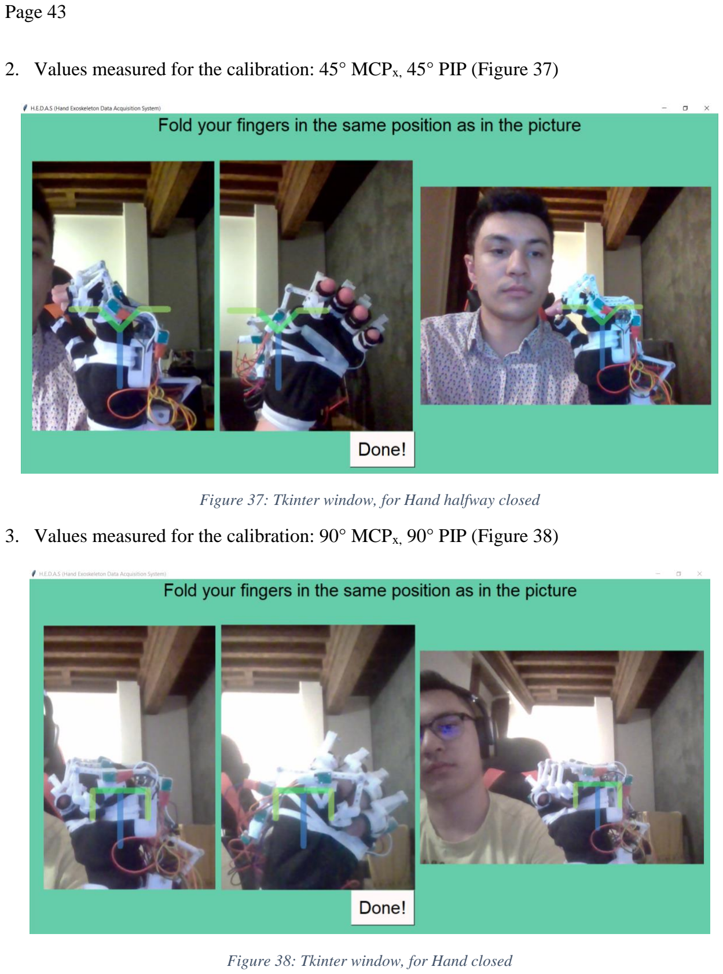
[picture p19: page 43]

2. Values measured for the calibration: 45° MCPx, 45° PIP (Figure 37)

Figure 37: Tkinter window, for Hand halfway closed

3. Values measured for the calibration: 90° MCPx, 90° PIP (Figure 38)

Figure 38: Tkinter window, for Hand closed

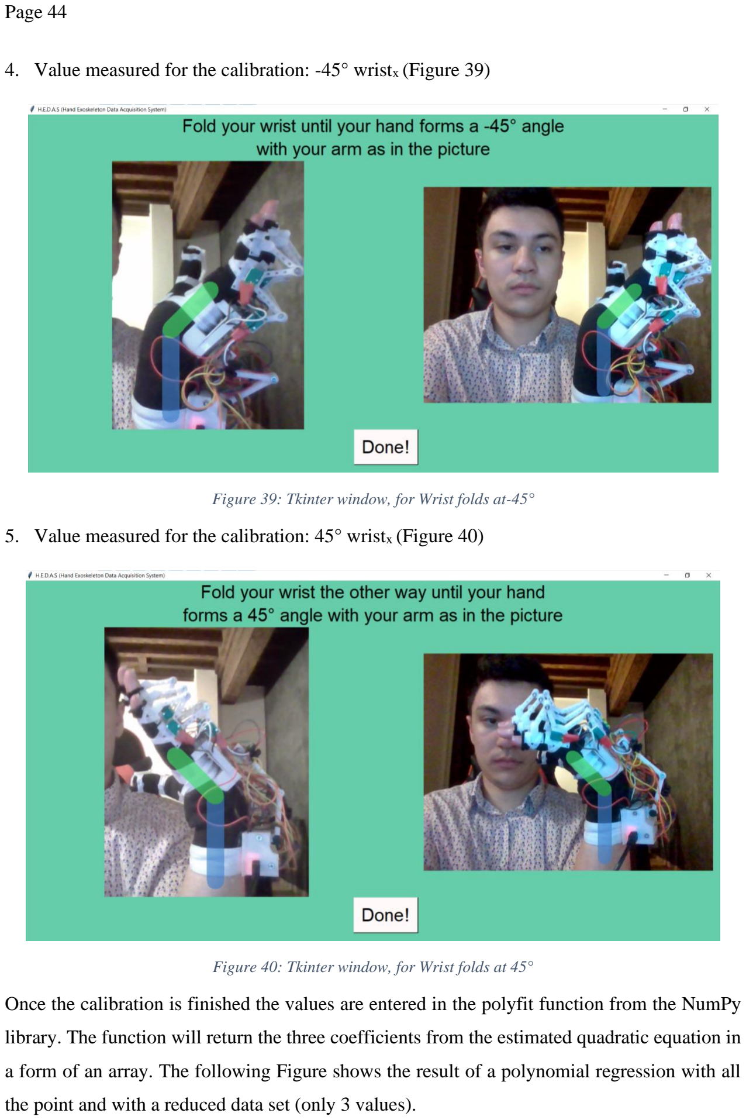
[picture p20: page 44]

4. Value measured for the calibration: -45° wristx (Figure 39)

Figure 39: Tkinter window, for Wrist folds at-45°

5. Value measured for the calibration: 45° wristx (Figure 40)

Figure 40: Tkinter window, for Wrist folds at 45°

Once the calibration is finished the values are entered in the polyfit function from the NumPy

library. The function will return the three coefficients from the estimated quadratic equation in

a form of an array. The following Figure shows the result of a polynomial regression with all

the point and with a reduced data set (only 3 values).

Figure 41: Plot of the regression using the Python polyfit function

The curves have identical shapes because the coefficient obtained are very similar:

Coefficients = [1.25324982e − 03, −5.19165129e − 01, 6.01762753e + 01]

Reduced set coefficients

= [ 1.18518519e − 03, −5.11111111e − 01, 6.00000000e + 01]

By averaging the difference between the two curves, the error of the approximation can be

obtained. The result for this specific example is -0.0016 which is negligible. These result of

course are theoretical, in practice, the user could perform an incorrect hand position with a bad

angle. It will introduce a large error since the approximation is power 2.

4.3.3 Saving the calibration with JSON

Once the calibration is done, the name of the calibration is asked in Figure 42. The goal was to

save the calibration to avoid calibrating each time the user wants to use the device.

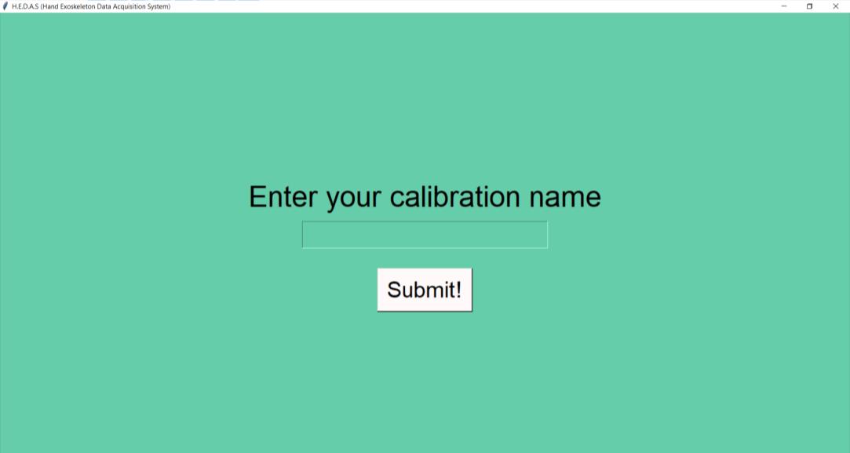
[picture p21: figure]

Figure 42: Tkinter window, asking for the name of the calibration

Now, to save the data from the calibration, there is multiple options such as a text file. However,

more than storing, the data should be easily accessible with Python. Therefore, a JSON file is

perfect for this purpose. A JSON file is a file consisting of a list of variables, each variable is

assigned a value. The value can be of any type: string, int, float or even an array (1D or 2D).

All the variables are separated by a comma, the name of the variables must be defined using

double quotes. It is followed by two points and the values of the variables. The Figure 43 shows

the JSON file created or open by the code. “Username” is the array containing the names with

the corresponding coefficients.

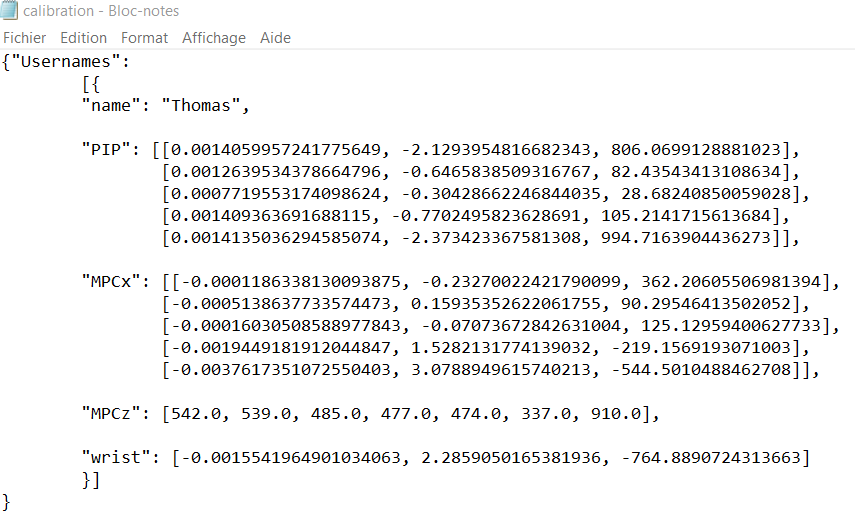
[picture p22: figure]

Figure 43: JSON file storing all the data of calibration

To store a new calibration, the following Python lines are used. First, the file must be opened,

and it is load within a variable:

if os.path.isfile(os.path.join(path + os.sep, "calibration.json")):

with open(os.path.join(path + os.sep, "sample.json")) as json_open:

data = json.load(json_open)

data being the variable where the json is load. Then, the file is modified by adding a

“Username” with all the information:

data['Usernames'].append({'name': name,'PIP': coeff_PIP,'MPCx': coeff_MCP,'MPCz': z_MC

P,'wrist': coeff_wrist})

If there exists no file, after the calibration, a JSON file with all the data must be created:

data = {}

data['Usernames'] = []

data['Usernames'].append({'name': name,'PIP': coeff_PIP,'MPCx': coeff_MCP,'MPCz': z_MC

P,'wrist': coeff_wrist})

And write in the a new file called “sample.json”:

with open(os.path.join(path + os.sep, "sample.json"), "w") as json_create:

json.dump(data, json_create)

data is defined, then it is filled with data and finally, the JSON file is created, and the data is

written inside it.

Now, to access the data in a JSON file, it must be open using its path then load the file. Then

the data can be accessed using the name of the variables. For instance, to get the PIP coefficient,

the line of code would be:

PIP_coeffs = data['Usernames'][0]['PIP']

with “0” being the first username.

Now, instead of calibrating, the user can use a calibration profile previously calibrated to his

hand.

4.3.4 Processing the data

The coefficients of the polynomial regression and the initial angles for the z-axis joints

obtained, the data coming from Arduino can be processed. Each type of joint has a different

process:

- PIP: poly_reg(coefficients PIP, new value of PIP)
- MCPx: poly_reg(coefficients MCPx, new value of MCPx)

- MCPz: potToAngle(initial value of MPCz) − potToAngle(new value of MCPz)
- wirstz: 180 − potToAngle(new value of wristz )
- wirstx: poly_reg(coeffs wristx, new value of wristz)
- DIP: PIPangle ∗ 0.88

with:

- poly_reg being a function that have for inputs the coefficient of the polynomial regression

and the raw values coming from the Arduino. It returns the angle of the joints

def poly_reg(coeff,val):

return coeff[0] * pow(val,2) + coeff[1]*val + coeff[2]

- potToAngle being a function that maps the values of the potentiometer to an actual angle.

To get MCPz, CMCx, CMCy, and wristz angles, their initial values subtracted by the data

received. The potentiometer can only rotate 330° and it returns a value between 0 and 1023,

therefore, the function is the following:

def potToAngle(val):

return val * 330 / (1023 + 15)

While being processed, the data is also reorganized in the angles array with a specific order:

Table 5: Organisation in the array of angles

PIP | MCPx | MCPz, CMCx, CMCy | wirstz | wirstx | DIP
0 → 4 | 5 → 9 | 10 → 16 | 17 | 18 | 19 → 23

4.4 Summary

The code is separated in multiple software and languages as every language has their advantages

and disadvantages. The role of Arduino is simple, collecting the data, organising it and sending

it. Python then receives the data to process it according to the calibration. The calibration is an

objectively short process that requires the full attention of the user where accuracy is key to the

good operation of the glove. The user has therefore the choice to save the calibration to avoid

repeat the same thing every time. In the next part, the Unity part of the code will be covered

since it concerns the testing part.

## Testing the glove

5.1 Testing with Unity for a fast visual verification

Unity real engine is a free software to develop mostly 3D games. It is widely known and

therefore, VR games can be easily created from scratch. Indeed, Oculus, a VR headset brand,

offers hand models in in their package for free. The model contains two hands, with all the

joints on the fingers with the complete degrees of freedom. The different phalanges can be

folded by changing locally the values of the joints’ angle. By posing the hand in various

position, a quick visual verification can be performed to verify the good operation of the glove.

The code is vastly explained, the code can be found in the Appendix B. Unity program.

5.1.1 Communicating with Python

Now, to communicate the values of the angles, the package “Socket” will be the bridge from

Python to Unity. Unity’s language is C#, but socket is one of library available. A socket is an

object that allows the user to open a connection with a machine, locally or remotely, and

exchange data with it. There is a Client-Server architecture, and there is usually one server and

several clients. The server is a machine which processes the client’s requests and possibly sends

him a response.

There are therefore two types of application installed on the machines:

- The “server”: listens while waiting for connections from clients.
- “client”: connect to the server.

For the client to connect to the server and vice versa, both needs two pieces of information:

- The server’s IP address, or its host name, which identifies a machine on the Internet or

on a local network.

- Host names are used to represent IP addresses more clearly

Here, the Python code is the server waiting for a connection from the client, Unity. Once the

request is sent from the client and the connection established, the two programs can start

exchanging data. The data sent to Unity are angles of every joint of the hand.

5.1.2 Moving the virtual hand

Before moving the hand, the hand must be in a known position, a “zero position” that the user

can reproduce easily. This position is the first performed during the calibration with the finger

near each other, the hand flat and the thumb as far as possible (Figure 36). This particular

position is important since the “zero angles” of the MCPz and CMCy,x are determined at this

moment.

Figure 44: Initial position in simulation

Therefore, once the programmed launched, the angles between the simulation and the glove are

going to match. The test consists on moving the hand in various poses to test the glove capability

to reproduce the movements, but the also the reactivity of the glove.

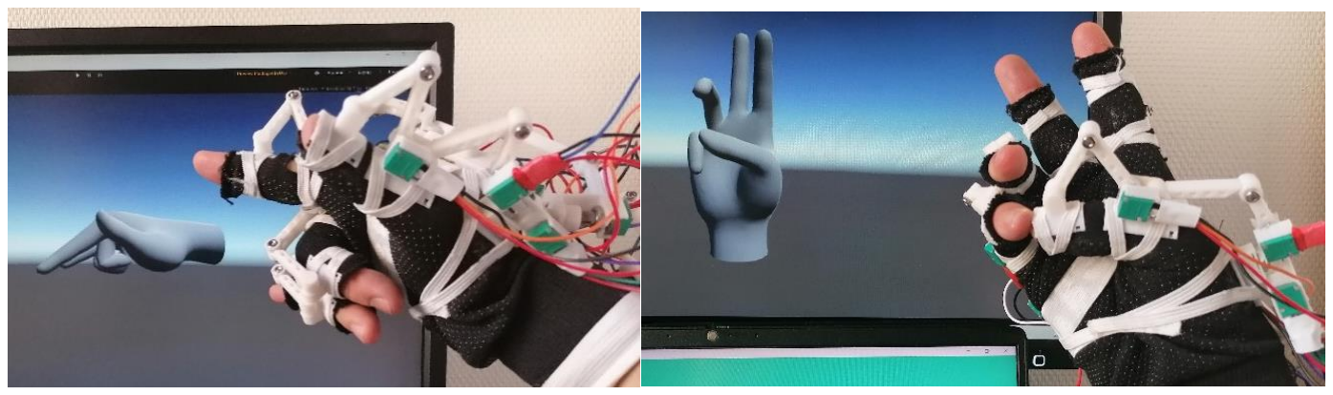
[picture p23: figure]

Figure 45: Testing different hand pose in Unity without using the wrist

5.1.3 Visual feedback

Overall, moving the hand while looking at the Unity simulation at the same time, the

movements of the hands are synchronised and accurate. Every joint in the simulation moves

according to your hand movements. Furthermore, the response time is immediate and there is

no noticeable latency.

5.1.4 DIP joint issues

Despite a great approximation of the DIP joint, some inaccuracies can be noticed, especially in

the three last pictures. Indeed, the DIP approximation does not work in certain condition, it is

possible that the DIP joint cannot move while the PIP joint is moving. This behaviour can

observe when one finger is folded without forcing to move the distal phalange (the tip of the

finger). This can be also observed with two, three or all the fingers as soon as the distal phalange

is not moving willingly. The negligence of the DIP was at first meant to save material, response

time and to have a better comfort. Therefore, by observing the movement of the hand, some

mechanical behaviours are noticeable. When the finger is forced to close the DIP, the finger

next to it move as well, especially the PIP. Therefore, from this, determining if the DIP moves

or not depending on the movement of the PIP joints of the finger nearby is possible. This is not

an easy task, and the approximation of the DIP angle should be for further work.

Unfortunately, it will not solve the problem when the DIP is fold against its will (pushed against

a table for example). Depending on the application, this solution can still be viable, VR games

for instance. However, in motion capture, the interaction with object is inevitable, which makes

the solution obsolete. The conclusion to this issue could be that the DIP should be also equipped

with sensors.

Anyway, concluding on the accuracy of the device with a visual verification is not enough and

further tests must be performed.

5.2 Accuracy test (and precision test)

In this section, four different tests will be performed on the glove to determine the accuracy and

the repeatability. The DIP is not test because a conclusion on its performances have already

been stated. Furthermore, the DIP is not measured and highly dependent on the performances

of the PIP.

5.2.1 Visual test with an overlay for MCPx, PIP and wristx

The test consists of using the same overlay as the calibration with 3 lines representing the hand

and phalanges. By superposing the hand and finger with the lines and displaying the data

obtained by the device, an idea of the accuracy of the glove can be obtained.

Figure 46: Test with the overlay at 30° and 60° for both joints

Although the results look very good, like Unity, this test is only a visual test. Indeed, it does

not provide a numerical value giving the real accuracy. Therefore, another test must be

performed to obtain the accuracy.

5.2.2 Comparison with an IMU

As seen in the literature review, multiple gloves use an Inertial Measurement Unit (IMU) to

measure the angle of the joints. Since the IMU was not part of the project anymore, it will be

used to measure the joint angles while wearing the glove. However, the I²C pins were taken by

the potentiometers which means that another board will be used. The Raspberry Pi was the

choice since it can be connected to the internet, Socket can be once more utilize to communicate

data. The setup of the test is shown in Figure 47. The IMU is strapped to the phalange and the

hand is parallel to the ground. Then, the finger is fold where the IMU is (the MCPx, and the

angle is measured by the accelerometer of the IMU while the Python code running on the

computer is sending the data to the Raspberry using Socket with a similar approach as sending

data to Unity.

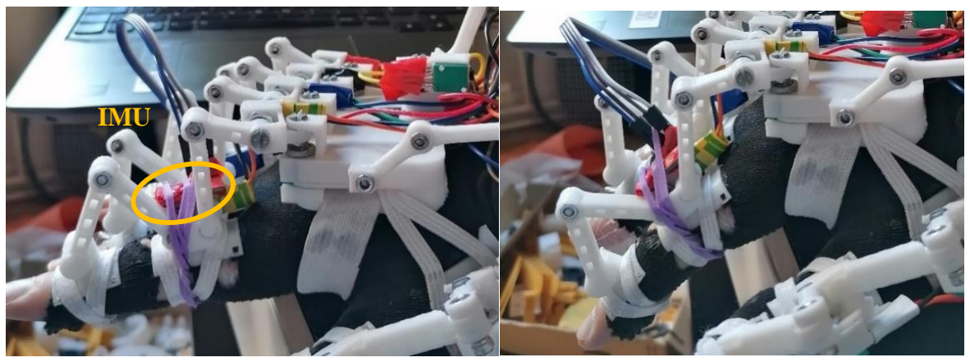
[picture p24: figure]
IMU

Figure 47: Accuracy test with an IMU connected to a Raspberry Pi

The glove and IMU were running at their own frequency, so to synchronise the data obtained

by the sensors, the data was collected when the Raspberry Pi received the glove information.

Furthermore, since both devices have a high rate of data collection, to avoid having too much

data to treat, only one value every 100 is kept. Once the experiment done, the data is saved in

a text file, analysed, and visualised in Excel. The result is shown in Figure 48.

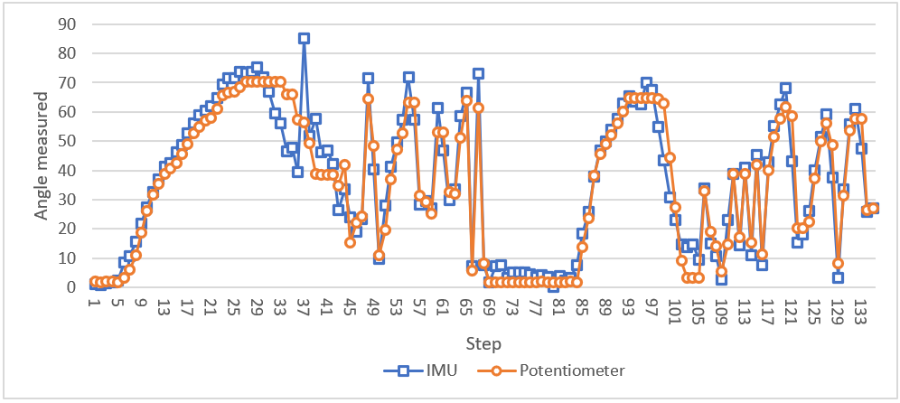
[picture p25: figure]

Figure 48: Comparison of measurements of the MPCx from the device and the IMU

The accuracy can be determined by averaging the difference between the values obtained by

the IMU and the glove. The accuracy obtained was ±5°, the difference is huge for this type of

device. Of course, this result is obtained without considering the inaccuracy of the IMU. Indeed,

the IMU values are very noisy despite the implementation of a median filter. The spikes and

errors in the IMU sensor can also be caused by the hand movements during the measure. The

hand moving is affecting the results of the IMU since it is sensitive to any movement whereas

the potentiometers values are only sensitive to the finger movement. To perfect the experiment,

the hand should not be moving, by being strapped to a table similarly to the test performed by

Salchow-Hömmen et al [1]. However, when the angles are increasing or decreasing slowly, the

curves merge and there is almost difference. Only the MCPx istested here, but since the solution

is the same for the PIP and the wrist, the conclusion is the same.

5.2.3 MCPz accuracy

To test the MCPz joints, a different method will be used, similar to the first one using an overlay.

Instead of using the overlay, a 3D part shaped with an angle of 20° has been printed to replace

it. The part goes between two fingers as shown in Figure 49 on the left picture. The angle

detected by the glove are printed as well as the two fingers’ MCPz value.

Figure 49: MPCz test with major and Index closed, then separated using a 20° 3D printed spacer

The result in both cases is very good. The repeatability is great as well because the body moving

up and down does not affect those sensors.

5.3 Repeatability

To test the precision, a repeatability test should be performed. The repeatability test is testing

the reliability of the device to successively obtain the same measure. From the accuracy test,

the ability to obtain the same measure should have already proven to be acceptable. However,

another test should be done to prove it.

The test consists in closing the hand five times, then to lay the hand flat on the table, and repeat

this process multiple times. The goal is to see if the glove is capable to measure the same value

in a similar position. The result of the test is in the following Figure 50, the test has been

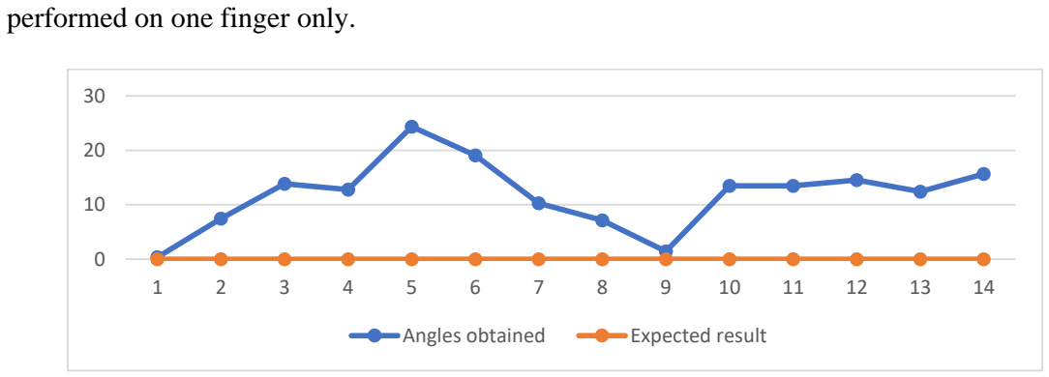
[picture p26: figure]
performed on one finger only.; Angles obtained; Expected result

Figure 50: Repeatability test on MCPx

For a successful repeatability test, the curve should be a constant line with the value 0. In Figure

50 however, the curve is far from a straight line, the values are not equal. The repeatability of

the MCPx is very poor, at least, when the hand is flat. The sensor cannot get the same data after folding the finger multiple times because the 3D parts are not really embedded to the glove.

The parts attached to the phalanges with elastic bands are not moving. However, for the main

body of the glove, the elastic band cannot hold it close to the hand and the body moves up and

down. Therefore, when the hand is closed, the body is close to the hand, but when the hand is

open and flat, the body is pushed and far away from the hand. Since the body is moving, the

values obtained from the sensors are different after folding the hand. For the repeatability, this

is not a good sign because the elasticity adds to the system some randomness, which explains

the terrible result obtained here. Acceptable results are obtained in the accuracy test mainly

because hand was in constant movement.

The repeatability of the PIP and the MCPz or wirstz are much better. The joint measured in the

z axis have a linear relation and they are not affected by up and down movement of the body.

The PIP, despite being measured in x, has shown a very good repeatability because the two

parts fixed to the phalanges are attached tightly on the finger.

5.4 Testing the device on participant’s hand

The glove is not meant to be used by only one person, which made the conception quite difficult.

The device has been tested on various hand size, slim or large, short, or long fingers. The glove

could adapt in every case with adults, but it does not fit a child’s hand because the parts are too

long for a small phalange.

5.5 Response time

The response time of this device can be measured by getting the sum of the time that one loop

takes in Arduino and Python. The Arduino loop takes 11ms to collect all the data, reorganizing

it and sending it to the Serial port, while a Python loop takes 0.5ms to receive the data, process

it and sending it. In total, the glove takes 11.5ms to send the data which is equivalent to a

frequency of 88.6Hz, which is impossible to notice by the human eye.

5.6 Summary

The result was satisfying with a great experience whilst moving the hand using UNITY. The

movement are synchronised and similar. However, from the simulation, the issue on the DIP

not moving exactly as expected has been discovered. For VR games, this is already quite good

as the user might not notice. Otherwise, the calibration could be extended to find more relations

between the DIP and the PIP joint. This solution cannot work when the distal phalange is forced.

Therefore, the best solution remains to have a sensor measuring the DIP as well.

Some accuracies and repeatability tests were performed. The result on the accuracy showed

some good results, whereas the repeatability was poor. The solution proposed was to attach the

3D printed parts to the hand much tighter to not allow parasite movements.

## Conclusion

6.1 Comparison to objectives

To conclude, all the objectives were completed. After searching in many articles, the

potentiometer was promising because it is accurate by itself, it is unsensitive to noise, it is the

most inexpensive sensor, and it is also the most accessible. Then, after designing and testing

multiple design by printing different part and different solution, a functional design has been

found. In the meantime, the interface to help the user to calibrate was developed. Accuracies

tests and a repeatability test were performed and allowed to conclude on the performance of the

glove. Finally, the aim of designing an open-source project the most inexpensive possible has

been successful as the artifact costed less than £20. The program is available in the GitHub link

in the appendices with the images for the calibration as well.

6.2 Critical appraisal

6.2.1 Performance

During the testing phases, the results in Unity seemed very promising. The hand and fingers

movements were replicated with high accuracy, at least, visually. The real accuracy has been

tested with multiple ways, using a webcam overlay, an IMU or 3D printed parts. The accuracy

was satisfying in every test, but the repeatability is very low. Since the 3D parts are not

completely fixed to the hand, some inaccuracies can be noticed. The way to attach the part to

the body can greatly improve.

6.2.2 Calibration

Although, the calibration with the webcam is a good idea, this is not the most accurate way to

have the perfect angles. Another method should be found to calibrate with the angle required

by the program, for instance using 3D parts to shape your finger with the good angles (similarly

to the test performed in part 5.2.3: MCPz accuracy. Most importantly, it would be even easier

to get rid of the calibration by designing a device that have a linear relationship between the

finger joints movement and the potentiometer movements.

6.2.3 Electrical components

Unfortunately, the wires are exposed, and they can be caught in something while moving.

Therefore, there should be a case or a piece of fabric to hide them and to protect them.

The size of the potentiometers could have been smaller, the glove is not heavy, but the design

was complicated because of the size of them.

6.3 Future work

The market research helped for this question since the questionnaire included a question about

other features that the device could have.

6.3.1 Adding the second hand

The project was focused on designing the glove for only one hand. The next step should be to

implement the second hand. A second Arduino with another Serial port could be a solution.

6.3.2 Adding a wireless communication

One of the most important features for this kind of device is the possibility to be wireless.

Carrying a wire is not adding a lot of value for the device. Indeed, the Oculus Rift or a webcam

with machine learning can measure joints angles with ease. Therefore, the advantage of wearing

a glove is the possibility to move around without restriction. However, a wire adds a restriction.

The device can still be used freely in space, but it all depends on the length of the wire.

The wireless communication can be performed easily with a Bluetooth module plugged to the

Arduino. Moreover, in part 3.3.2, the power consumption has been computed and it has been

proven to be very low. An external battery could be used in this case, and it could power the

system for a long time depending on the capacity.

6.3.3 Adding a haptic feedback

A haptic feedback is a physical feedback felt by the user when a force is applied against the

virtual model. For virtual reality, some gloves have the motors that drives the fingertips if a

player touches an object, adding resistance to its movements to simulate the sensation of touch.

Some projects use a vibrator on the fingertips to simulate the touch as well, but it is less

immersive. Another option is using electromagnetic bars which stops the folding when supplied

with electricity.

6.3.4 PCB (Printed circuit board)

A PCB is a support, making it possible to maintain and electrically connect a set of electronic

components to one another, with the aim of producing a complex electronic circuit. PCBs are designed by the customer, and it will be manufactured by a company. Therefore, the advantage

of this is to choose the size, the components which can reduce the price and the waste. However,

it usually is cheaper if multiple PCB are manufactured in one order.

The circuit for this glove should be composed of a microcontroller, a multiplexer of 16 inputs

and a USB adapter for communication and powering.

## References

[1] Park Jaeyoung, Hwang Inchan and Lee Woochan. (2020). Wearable Robotic Glove

Design Using Surface-Mounted Actuators. Frontiers in Bioengineering and

Biotechnology.

[2] S. Ghate, L. Yu, K. Du, C. T. Lim and J. C. Yeo. (2020 ). Sensorized fabric glove as game

controller for rehabilitation. IEEE SENSORS. Rotterdam, Netherlands .

[3] Y. Mori and M. Toyonaga. (2018). Data-Glove for Japanese Sign Language Training

System with Gyro-Sensor. Joint 10th International Conference on Soft Computing and

Intelligent Systems (SCIS) and 19th International Symposium on Advanced Intelligent

Systems (ISIS), Toyama, Japan.

[4] sparkfun.com. Flex sensor SEN-08606, Spectra Symbol. [online] Available at:

https://www.sparkfun.com/products/8606

[5] aliexpress.com, eyewink 001. Flex sensor SEN-08606, Spectra Symbol. [online]

Available at: https://fr.aliexpress.com/item/4001053241357.html?spm=a2g0o.product

list.0.0.5c193458sMzpef&algo_pvid=1f98a97a-4e2d-46db-

a937474ab2faa327&algo_expid=1f98a97a-4e2d-46db-a937-

474ab2faa3270&btsid=2100bdd716182437770148171ef85b&ws_ab_test=searchweb0_0,

searchweb201602_,searchweb201603_

[6] aliexpress.com. Slider potentiometer 10kOhm. [online] Available at:

https://fr.aliexpress.com/item/32990553553.html?spm=a2g0s.9042311.0.0.41f06c374vhz

gE (https://fr.aliexpress.com/item/32990553553.html?spm=a2g0s.9042311.0.0.41f06c374vhzgE)

[7] aliexpress.com. IMU 6-axis. [online] Available at:

https://fr.aliexpress.com/item/33009159455.html?spm=a2g0o.productlist

.0.0.386745a23l78xx&algo_pvid=f037dd36-b9f5-40ae-

815a1b38723fd24d&algo_expid=f037dd36-b9f5-40ae-815a-

1b38723fd24d1&btsid=2100bdec16182427367641348ef252&ws_ab_test=searchweb0_0,

searchweb201602_,searchweb201603_

[8] aliexpress.com. Rotary potentiometer 10kOhm. [online] Available at:

https://fr.aliexpress.com/item/33011428749.html?spm=a2g0s.9042311.0.0.41f06c374vhz

gE (https://fr.aliexpress.com/item/33011428749.html?spm=a2g0s.9042311.0.0.41f06c374vhzgE)

[9] NotionTheory, Medium.com.(2017) “BUILDING A HAPTIC FEEDBACK GLOVE FOR

VIRTUAL REALITY “, [online] Available at:

<https://medium.com/@notiontheory/building-a-haptic-feedback-glovefor-virtual-reality-

77232999a2d7>.

[10] M. Ariyanto, R. Ismail, A. Nurmiranto, W. Caesarendra, Paryanto and J. Franke.

(2016). Development of a low cost anthropomorphic robotic hand driven by modified

glove sensor and integrated with 3D animation. IEEE EMBS Conference on Biomedical

Engineering and Sciences (IECBES). Kuala Lumpur, Malaysia.

[11] Ivan Petrov. (https://www.deviceplus.com/author/ivan/) (2016). (https://www.deviceplus.com/author/ivan/) ARDUINO BLUETOOTH GLOVES PART 2 – PUTTING

EVERYTHING TOGETHER, deviceplus.com, [online] Available at:

<https://www.deviceplus.com/arduino/bluetooth-gloves-part-2/>.

[12] 5DT (2004). Data glove Ultra. [online] Available at:

<http://www.5dt.com/downloads/dataglove/ultra/5DT%20Data%20Glove%20Ultra%20M

anual%20v1.3.pdf (http://www.5dt.com/downloads/dataglove/ultra/5DT%20Data%20Glove%20Ultra%20Manual%20v1.3.pdf) >.

[13] Y. Park, J. Lee and J. Bae. (2015). Development of a Wearable Sensing Glove for

Measuring the Motion of Fingers Using Linear Potentiometers and Flexible Wires. vol.

11, no. 1, pp. 198-206, in IEEE Transactions on Industrial Informatics.

[14] J. Connolly, J. Condell, B. O’Flynn, J. T. Sanchez and P. Gardiner. (2018). IMU

Sensor-Based Electronic Goniometric Glove for Clinical Finger Movement Analysis. vol.

18, no. 3, pp. 1273-1281. in IEEE Sensors Journal.

[15] Salchow-Hömmen, Christina; Callies, Leonie; Laidig, Daniel et al. (2019). A Tangible

Solution for Hand Motion Tracking in Clinical Applications. Technische Universität

Berlin.

[16] Hrabia, Christopher-Eyk & Wolf, Katrin & Wilhelm, Mathias. (2013). Whole Hand

Modeling Using 8 Wearable Sensors: Biomechanics for Hand Pose Prediction.

International Conference Proceeding Series.

[17] Mehlmanmedical.com. (2021). Wrist and hand – Abduction, adduction, opposition –

MEHLMANMEDICAL. [online] Available at: <https://mehlmanmedical.com/wrist-and-

hand-abduction-adduction-opposition/>.

[18] Ti.com. (2021). [online] Available at:

<https://www.ti.com/lit/ds/symlink/cd74hc4067.pdf?ts=1628201499826&ref_url=https%

253A%252F%252Fwww.google.com%252F>.

## Appendices

A. GitHub link

This link goes to a GitHub project where the Python and Arduino are:

https://github.com/ThAUJAS/H.E.D.A.S-Exoskeleton-glove-sensor-

B. Unity program

Since the Unity program is not explained in the dissertation, the code is provided.

using System.Collections;
using System.Collections.Generic;
using System.Net;
using System.Net.Sockets;
using System.Text;
using UnityEngine;
using System.Threading;

public class CSharpForGIT : MonoBehaviour
{
Thread mThread;
public string connectionIP = "127.0.0.1"; public int connectionPort = 25001; IPAddress localAdd;
TcpListener listener;
TcpClient client;
float[] receivedData = new float[23];

bool running;

//updates the values of the joints
private void Update()
{
GameObject thumb1 = GameObject.Find("b_r_thumb1");
GameObject thumb2 = GameObject.Find("b_r_thumb2");
GameObject thumb3 = GameObject.Find("b_r_thumb3"); thumb3.transform.localRotation = Quaternion.Euler(new Vector3(0,0,-receivedData[0]));
thumb2.transform.localRotation = Quaternion.Euler(new Vector3(0,receiv edData[10],-receivedData[5]+20)); thumb1.transform.localRotation = Quaternion.Euler(new Vector3(received Data[16]-7,receivedData[10]-10,receivedData[15])); GameObject index1 = GameObject.Find("b_r_index1");
GameObject index2 = GameObject.Find("b_r_index2");
GameObject index3 = GameObject.Find("b_r_index3"); index3.transform.localRotation = Quaternion.Euler(new Vector3(0,0,-receivedData[19]));

index2.transform.localRotation = Quaternion.Euler(new Vector3(0,0,-receivedData[1]));
index1.transform.localRotation = Quaternion.Euler(new Vector3(0,receiv edData[11]+5,-receivedData[6])); GameObject middle1 = GameObject.Find("b_r_middle1");
GameObject middle2 = GameObject.Find("b_r_middle2");
GameObject middle3 = GameObject.Find("b_r_middle3"); middle3.transform.localRotation = Quaternion.Euler(new Vector3(0,0,-receivedData[20]));
middle2.transform.localRotation = Quaternion.Euler(new Vector3(0,0,-receivedData[2]));
middle1.transform.localRotation = Quaternion.Euler(new Vector3(0,recei vedData[12],-receivedData[7])); GameObject ring1 = GameObject.Find("b_r_ring1");
GameObject ring2 = GameObject.Find("b_r_ring2");
GameObject ring3 = GameObject.Find("b_r_ring3"); ring3.transform.localRotation = Quaternion.Euler(new Vector3(0,0,-receivedData[21]));
ring2.transform.localRotation = Quaternion.Euler(new Vector3(0,0,-receivedData[3]));
ring1.transform.localRotation = Quaternion.Euler(new Vector3(0,receiv edData[13]-3,-receivedData[8])); GameObject pinky0 = GameObject.Find("b_r_pinky0");
GameObject pinky1 = GameObject.Find("b_r_pinky1");
GameObject pinky2 = GameObject.Find("b_r_pinky2");
GameObject pinky3 = GameObject.Find("b_r_pinky3"); pinky3.transform.localRotation = Quaternion.Euler(new Vector3(0,0,-receivedData[22]));
pinky2.transform.localRotation = Quaternion.Euler(new Vector3(0,0,-receivedData[4]));
pinky1.transform.localRotation = Quaternion.Euler(new Vector3(0,receiv edData[14]-10,-receivedData[9])); pinky0.transform.localRotation = Quaternion.Euler(new Vector3(-5,10,0));
GameObject wrist = GameObject.Find("b_r_wrist"); wrist.transform.localRotation = Quaternion.Euler(new Vector3(0,-receivedData[17],-receivedData[18])); }

private void Start()
{
ThreadStart ts = new ThreadStart(GetInfo); mThread = new Thread(ts);
mThread.Start();
}

//connects to Python
void GetInfo()
{

localAdd = IPAddress.Parse(connectionIP);
listener = new TcpListener(IPAddress.Any, connectionPort); listener.Start();

client = listener.AcceptTcpClient();

while (true)
{
SendAndReceiveData();
}
listener.Stop();
}

//receiving the data and converting it
void SendAndReceiveData()
{
NetworkStream nwStream = client.GetStream(); byte[] buffer = new byte[client.ReceiveBufferSize]; print("hello");

//---receiving Data from the Host----
//Getting data in Bytes from Python
int bytesRead = nwStream.Read(buffer, 0, client.ReceiveBufferSize); //Converting byte data to string
string dataReceived = Encoding.UTF8.GetString(buffer, 0, bytesRead);

if (dataReceived != null)
{
//---Using received data---
receivedData = StringToArray(dataReceived); //<-
- assigning receivedPos value from Python }
}

public static float[] StringToArray(string sVector)
{
// Remove the parentheses
if (sVector.StartsWith("[") && sVector.EndsWith("]")) {
sVector = sVector.Substring(1, sVector.Length - 2); }

// split the items
string[] sArray = sVector.Split(',');

// store as a float[]
float[] result = new float[23];

for(int i=0; i<23; i++){

result[i] = float.Parse(sArray[i])/1000; }
return result;
}
}

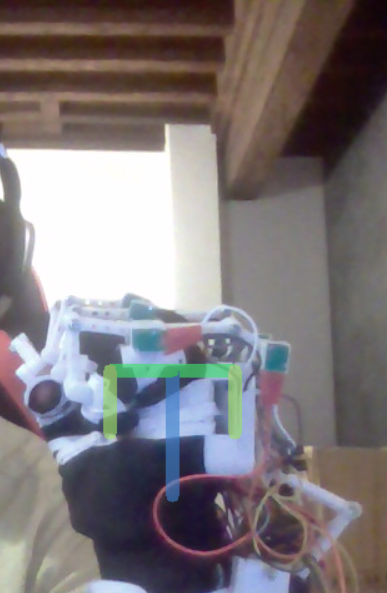
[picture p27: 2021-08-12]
image/90_finger.png

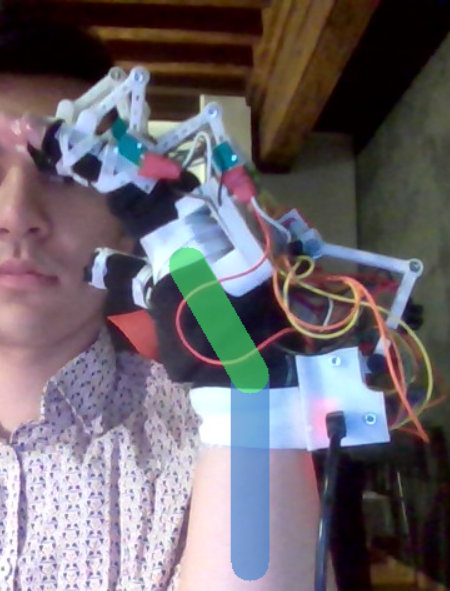
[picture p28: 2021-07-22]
image/30_wrist.png

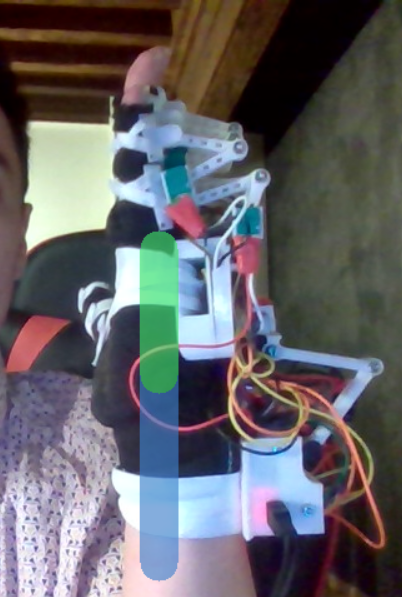
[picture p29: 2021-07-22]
image/open_profile.png

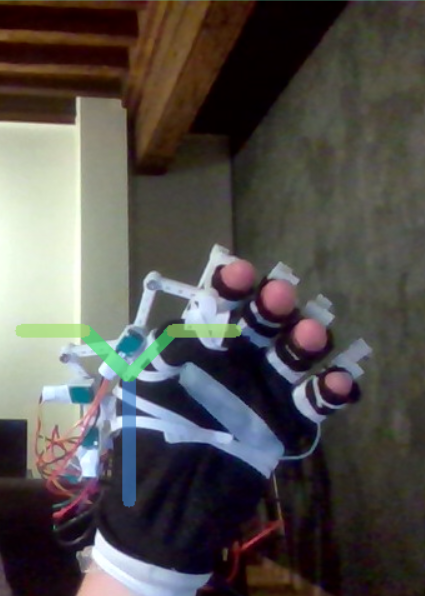
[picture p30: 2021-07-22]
image/45_thumb.png

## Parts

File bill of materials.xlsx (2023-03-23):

Part | Poduct descriptions | Price | Link
15 to 20 rotary potentiometers | 3.98 | 3.98 | https://fr.aliexpress.com/item/33011428749.html?spm=a2g0o.cart.0.0.18443c00iMQmSW&mp=1
Arduino nano | 4 | 4 | https://fr.aliexpress.com/item/4000587268145.html
Multiplexer | 1.4 | 1.4 | https://fr.aliexpress.com/item/32787406285.html?spm=a2g0o.cart.0.0.651a3c00y2Xxtl&mp=1
IMU | 1.9 | 1.9 | https://fr.aliexpress.com/item/32648074007.html
Jumpers Female to Female of 20/30 cm | 3.87 | 3.87 | https://fr.aliexpress.com/item/32898199540.html?spm=a2g0o.cart.0.0.651a3c00y2Xxtl&mp=1
Wire-nut connector | 0.65 | 0.65 | https://fr.aliexpress.com/item/32936640163.html?spm=a2g0o.cart.0.0.651a3c00y2Xxtl&mp=1
Mini USB cable 1.5m or 3m | 3.96 | 3.96 | https://fr.aliexpress.com/item/32870987678.html
Elastics | 1.21 | 1.21 | https://fr.aliexpress.com/item/4001123233641.html?spm=a2g0o.cart.0.0.651a3c00y2Xxtl&mp=1
nut + screw m3x8 | 2.26 | 2.26 | https://fr.aliexpress.com/item/10000150053486.html?mp=1
Total = | 21.83

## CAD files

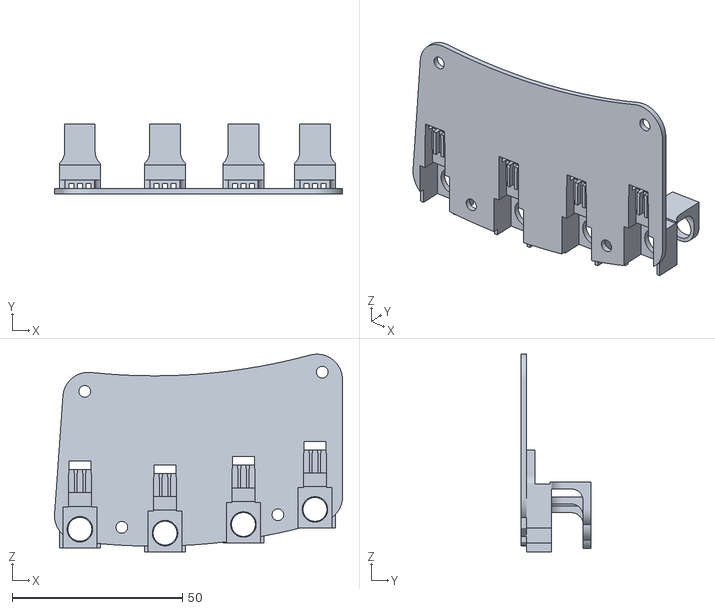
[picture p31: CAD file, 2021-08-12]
STL/plaque main v21.stl
84.5 x 20.5 x 58.0

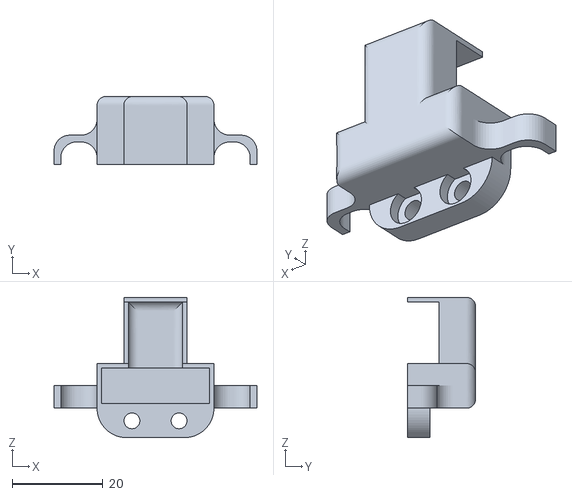
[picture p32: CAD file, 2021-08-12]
STL/fil imu.stl
44.8 x 15.1 x 31.0

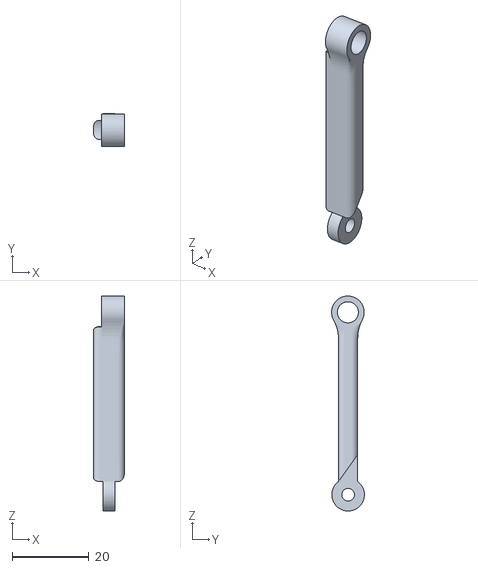
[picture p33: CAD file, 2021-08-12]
STL/bar connection 2 wrist.stl
8.00 x 8.56 x 56.0

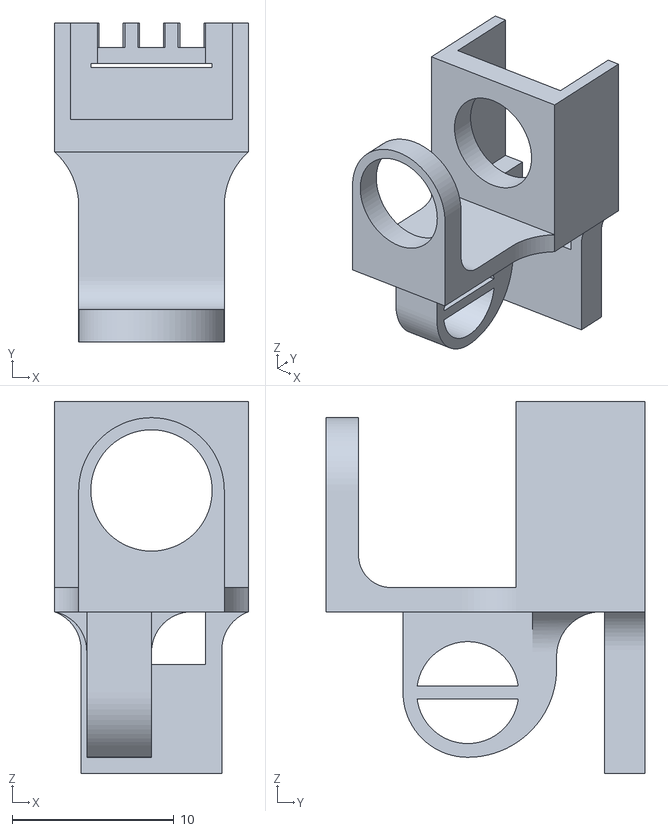
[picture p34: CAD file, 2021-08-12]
STL/revolute joint holder MPC x v25.stl
12.0 x 19.7 x 23.0

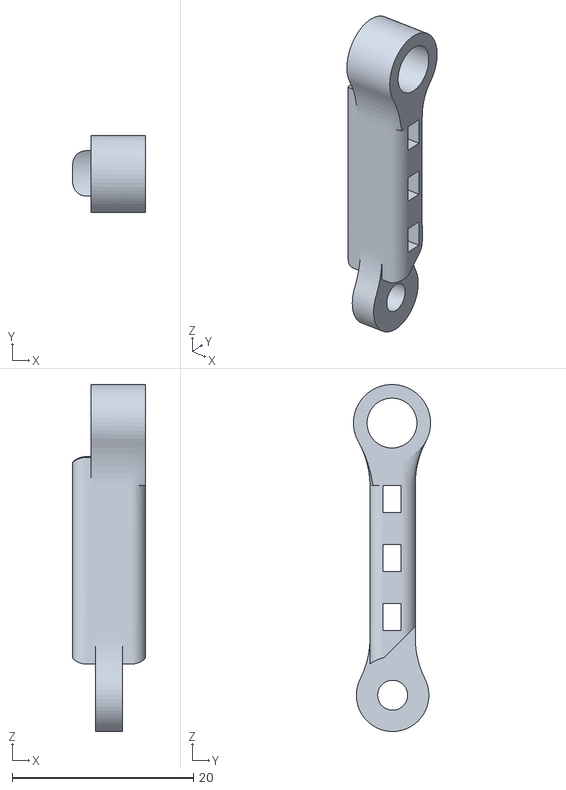
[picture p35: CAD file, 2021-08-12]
STL/bar connection 2.stl
8.00 x 8.49 x 38.2

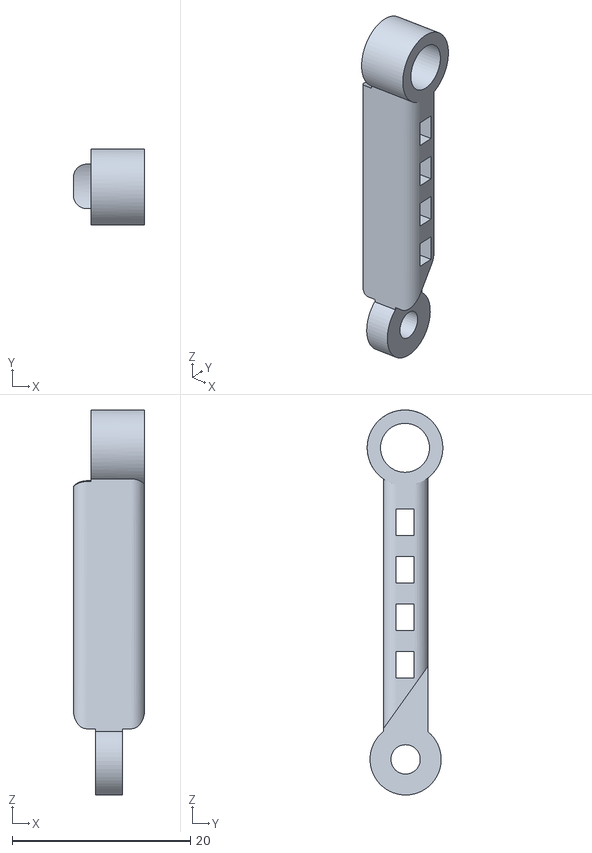
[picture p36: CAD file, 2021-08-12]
STL/bar connection 2 40.stl
8.00 x 8.50 x 43.2

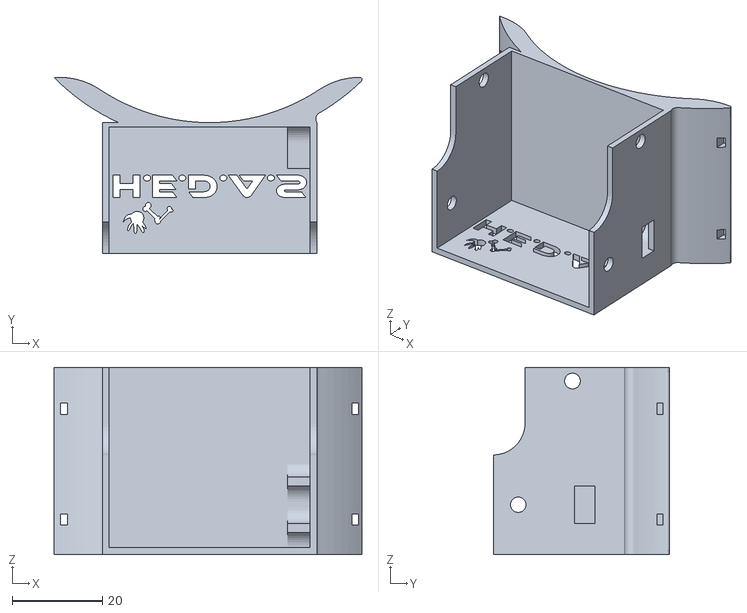
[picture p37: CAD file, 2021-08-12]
STL/box arduimux.stl
68.2 x 39.0 x 41.4

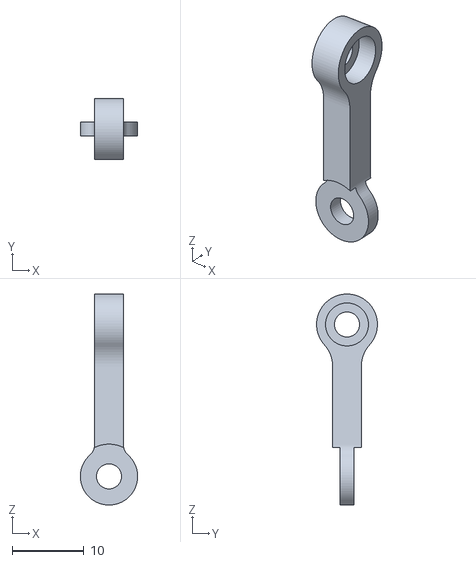
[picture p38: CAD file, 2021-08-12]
STL/test bar.stl
7.99 x 8.49 x 29.4

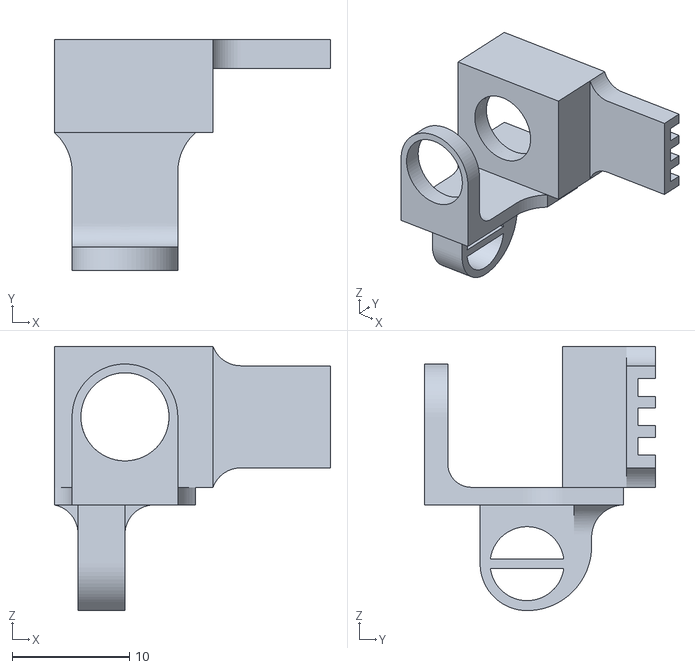
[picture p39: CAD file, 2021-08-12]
STL/wire holder CMC x v3.stl
23.5 x 19.7 x 22.5

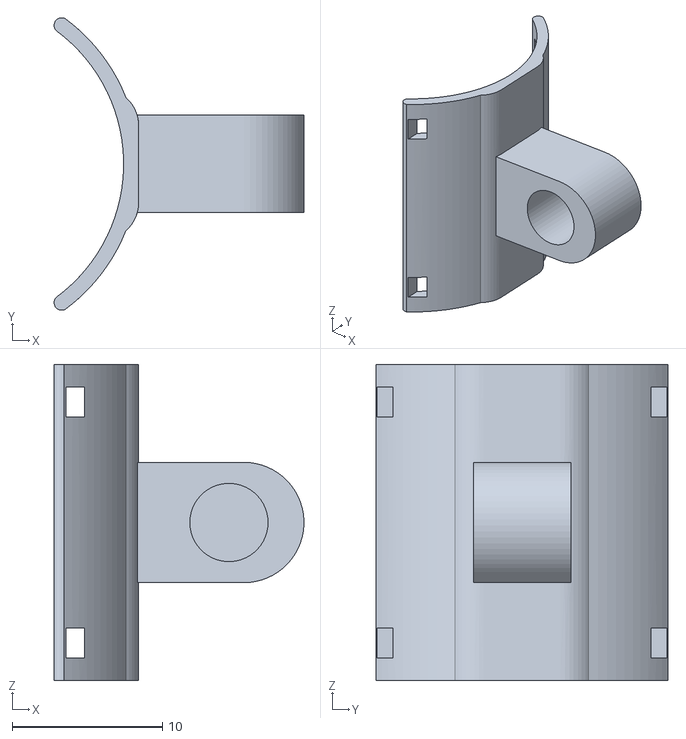
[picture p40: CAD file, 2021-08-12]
STL/revolute joint holder PIP v1.stl
16.6 x 19.4 x 21.0

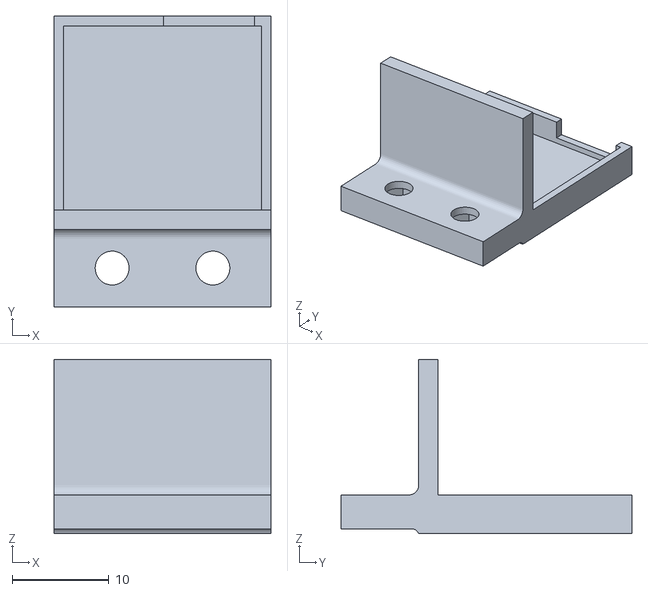
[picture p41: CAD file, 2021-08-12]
STL/imu box.stl
22.4 x 30.0 x 18.0

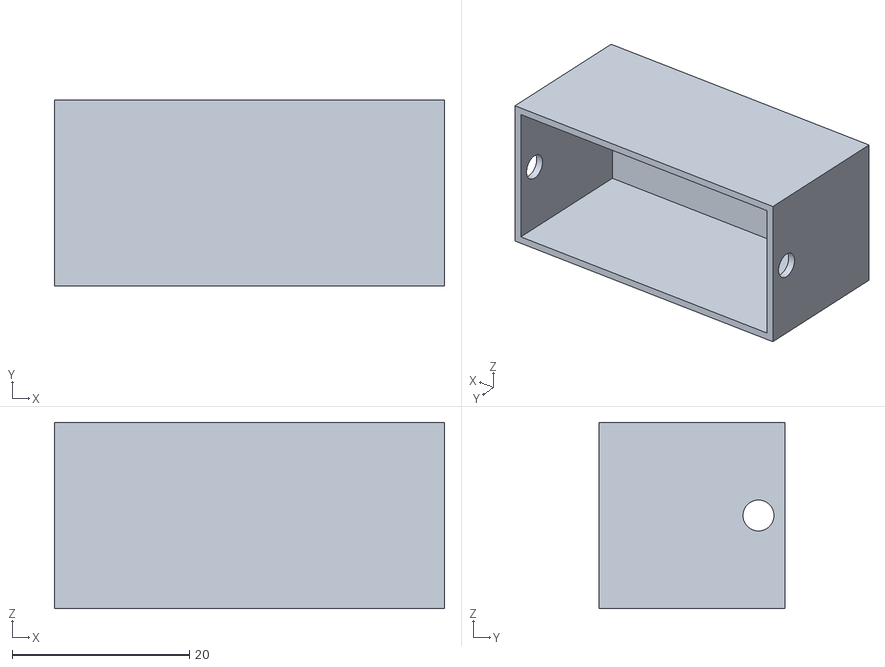
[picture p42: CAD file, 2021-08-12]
STL/mux box.stl
44.0 x 21.0 x 21.0

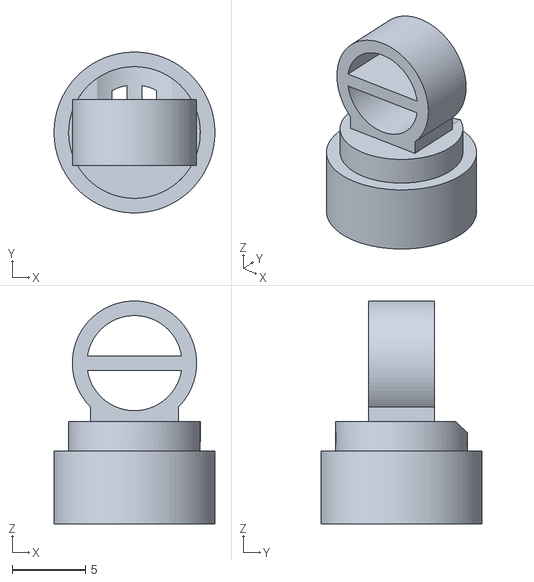
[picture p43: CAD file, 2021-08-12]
STL/bar attached.stl
11.0 x 11.0 x 15.2

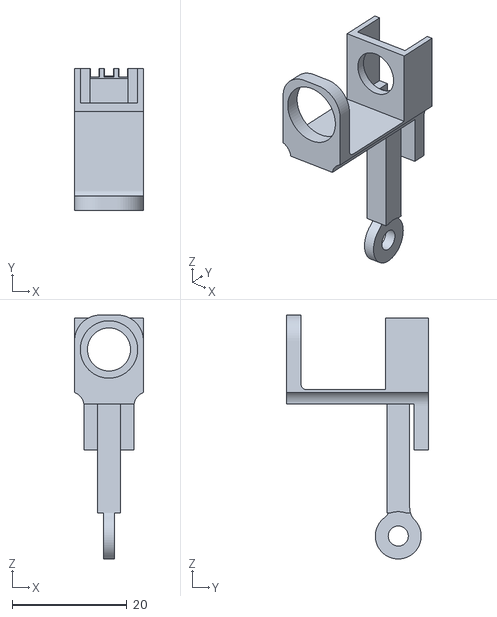
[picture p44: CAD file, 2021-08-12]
STL/cmc y v11.stl
12.0 x 24.7 x 42.5

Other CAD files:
STL/pin PIP v4.stl
STL/wire holder wrist z v6.stl
STL/cover arduino.stl
STL/wire holder CMC z v5.stl
STL/CE3_plaque.3mf
STL/CMCz v3.f3z
STL/accuracy test.stl
STL/bar connection 2 small.stl
STL/bar connection v49.stl
STL/bar connection wrist.stl
STL/calibration 45.stl
STL/calibration 60.stl
STL/calibration 90.stl
STL/cmc y v8.stl
STL/mux box cover.stl
STL/plaque bas.stl
STL/plaque up.stl
STL/plaque.stl
STL/rev holder.stl
STL/test bar 2.stl
STL/test bar cmc.stl
STL/test barrr.stl
STL/test cmc x bar.stl
STL/uper plaque.stl
STL/wire holder MPC z v1.stl
STL/wire holder MPC z v26.stl
STL/wire holder PIP v10.stl
STL/wire holder wrist z v3.stl
STL/wire holder wrist.stl

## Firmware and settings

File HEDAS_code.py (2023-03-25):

# Libraries
from tkinter import * 
from tkinter import messagebox
import PIL
from PIL import Image,ImageTk
from numpy.lib.function_base import angle
import socket
import serial
import serial.tools.list_ports
from threading import Thread
from time import sleep, time
import numpy as np
import trace
import json
import sys
import os
import cv2
import math

# creates a Tk() object
master = Tk()

#global variables
ready = False
arduino = ""
angles_raw = [0]*19
angles = [0]*23
unity = False
done = True
val = 0
sock = 0
s = 0 
button_web = 0

# Variables for calibration
angle_calibration_MCP = [0,45,80]
angle_calibration_PIP = [0,45,90]
angle_calibration_wrist = [-45,0,45]
x_MCP = [[0] * 3 for i1 in range(5)]
x_PIP = [[0] * 3 for i1 in range(5)]
z_MCP = [0]*7
wrist_val = [0] * 3
coeff_MCP = [[0] * 3 for i1 in range(5)]
coeff_PIP = [[0] * 3 for i1 in range(5)]
coeff_wrist = [0] * 3

#webcam variables
color_prox = (255, 255, 0)
color_meta = (0, 255, 0)
color_hand = (0, 0, 255)
alpha = 0.4
thickness = 10
show_cam = False
cap = 0

#----------------------------function/thread for the interface--------------------------#
# 1) Main page: asking for the Port to which the Arduino is connected
def interface():
    global master
    master.title("H.E.D.A.S (Hand Exoskeleton Data Acquisition System)")
    master.state('zoomed')
    master.config(bg = 'medium aquamarine')

    ports = serial.tools.list_ports.comports(include_links=False) #looking for the acive ports

    if (len(ports) != 0): # we found a port
        label = Label(master, text ="Choose the port to which the device is connected:", font=("Abadi MT Condensed Extra Bold", 30), bg = 'medium aquamarine').pack(pady = 150)
        for port in ports :  # we display the ports' name on buttons
            Button(master, text = port.device, command = lambda : Calibration(port.device), font=("Abadi MT Condensed Extra Bold", 30), bg = 'snow').pack(pady = 20)
    else:  # else we need to connect the device and relaunch the program
        label = Label(master, text = "No port found. Connect a device and relaunch the program", font=("Abadi MT Condensed Extra Bold", 30), bg = 'medium aquamarine').pack(pady = 300)

# 2) Page where there is a choice between calibrating and using a previous calibration      
def Calibration(portDevice):
    global master,ready,arduino
    arduino = serial.Serial(port=portDevice, baudrate=115200, timeout=.1) # the arduino is connected to Python
    ready = True # the read_function can start reading the Arduino data
    eraseWidget()
    # checking if a file exists
    if os.path.isfile(os.path.join(path + os.sep, "sample.json")):
        Label(master, text ="Do you want to calibrate or use a previous calibration profile?", font=("Abadi MT Condensed Extra Bold", 30), bg = 'medium aquamarine').pack(pady = 150)
        Button(master, text = "New calibration", command = calibration, font=("Abadi MT Condensed Extra Bold", 30), bg = 'snow').pack(pady = 10)
        Button(master, text = "Use a user calibration profile", command = NoCal, font=("Abadi MT Condensed Extra Bold", 30), bg = 'snow').pack(pady = 50)
    else:
        Label(master, text ="You didn't calibrate yet... Create a new calibration", font=("Abadi MT Condensed Extra Bold", 30), bg = 'medium aquamarine').pack(pady = 150)
        Button(master, text = "New calibration", command = calibration, font=("Abadi MT Condensed Extra Bold", 30), bg = 'snow').pack(pady = 10)

# 3) Calibration process with 5 steps
def calibration():
    global master, val, show_cam,cap,thread1, button_web
    eraseWidget()

    if val == 0:
        Label(master, text ="Put your hand flat with the thumb as far as possible from the fingers", font=("Abadi MT Condensed Extra Bold", 30), bg = 'medium aquamarine').pack()
        Label(master, text ="And your hand must be aligned with your arm", font=("Abadi MT Condensed Extra Bold", 30), bg = 'medium aquamarine').pack()
        image1 = Image.open(os.path.join(path + os.sep, "image","open_profile.png"))
        image2 = Image.open(os.path.join(path + os.sep, "image","open_face.png"))
        test1 = ImageTk.PhotoImage(image1)
        label1 = Label(image=test1, bg = 'medium aquamarine')
        label1.image = test1
        test2 = ImageTk.PhotoImage(image2)
        label2 = Label(image=test2, bg = 'medium aquamarine')
        label2.image = test2
        label1.place(x=225,y = master.winfo_height()/2,anchor = CENTER)
        label2.place(x=650,y = master.winfo_height()/2,anchor = CENTER)
        if not show_cam:
            Button(master, text = "Show the webcam", command = lambda : show(), font=("Abadi MT Condensed Extra Bold", 30), bg = 'snow').place(x=1200,y = master.winfo_height()/2,anchor = CENTER)
            Label(master, text ="This will return the video of your webcam (if you have a one).", font=("Abadi MT Condensed Extra Bold", 15), bg = 'medium aquamarine').place(x=1200,y = master.winfo_height()/2+55,anchor = CENTER)
            Label(master, text ="The same indicator as in the picture will show on the video", font=("Abadi MT Condensed Extra Bold", 15), bg = 'medium aquamarine').place(x=1200,y = master.winfo_height()/2+95,anchor = CENTER)
            Label(master, text ="to help you positioning your fingers.", font=("Abadi MT Condensed Extra Bold", 15), bg = 'medium aquamarine').place(x=1200+25,y = master.winfo_height()/2+135,anchor = CENTER)
            Label(master, text ="Opening the webcam can take a couple of seconds", font=("Abadi MT Condensed Extra Bold", 15), bg = 'medium aquamarine').place(x=1200+25,y = master.winfo_height()/2+175,anchor = CENTER)
   
    if val == 1:
        Label(master, text ="Fold your fingers in the same position as in the picture", font=("Abadi MT Condensed Extra Bold", 30), bg = 'medium aquamarine').pack()
        image1 = Image.open(os.path.join(path + os.sep,"image", "45_finger.png"))
        image2 = Image.open(os.path.join(path + os.sep,"image", "45_thumb.png"))
        test1 = ImageTk.PhotoImage(image1)
        label1 = Label(image=test1, bg = 'medium aquamarine')
        label1.image = test1
        test2 = ImageTk.PhotoImage(image2)
        label2 = Label(image=test2, bg = 'medium aquamarine')
        label2.image = test2
        label1.place(x=225,y = master.winfo_height()/2,anchor = CENTER)
        label2.place(x=650,y = master.winfo_height()/2,anchor = CENTER)
        if not show_cam:
            Button(master, text = "Show the webcam", command = lambda : show(), font=("Abadi MT Condensed Extra Bold", 30), bg = 'snow').place(x=1200,y = master.winfo_height()/2,anchor = CENTER)
            Label(master, text ="This will return the video of your webcam (if you have a one).", font=("Abadi MT Condensed Extra Bold", 15), bg = 'medium aquamarine').place(x=1200,y = master.winfo_height()/2+55,anchor = CENTER)
            Label(master, text ="The same indicator as in the picture will show on the video", font=("Abadi MT Condensed Extra Bold", 15), bg = 'medium aquamarine').place(x=1200,y = master.winfo_height()/2+95,anchor = CENTER)
            Label(master, text ="to help you positioning your fingers.", font=("Abadi MT Condensed Extra Bold", 15), bg = 'medium aquamarine').place(x=1200+25,y = master.winfo_height()/2+135,anchor = CENTER)
            Label(master, text ="Opening the webcam can take a couple of seconds", font=("Abadi MT Condensed Extra Bold", 15), bg = 'medium aquamarine').place(x=1200+25,y = master.winfo_height()/2+175,anchor = CENTER)
    
    if val == 2:
        Label(master, text = "Fold your fingers in the same position as in the picture", font=("Abadi MT Condensed Extra Bold", 30), bg = 'medium aquamarine').pack()
        image1 = Image.open(os.path.join(path + os.sep,"image", "90_finger.png"))
        image2 = Image.open(os.path.join(path + os.sep,"image", "90_thumb.png"))
        test1 = ImageTk.PhotoImage(image1)
        label1 = Label(image=test1, bg = 'medium aquamarine')
        label1.image = test1
        test2 = ImageTk.PhotoImage(image2)
        label2 = Label(image=test2, bg = 'medium aquamarine')
        label2.image = test2
        label1.place(x=225,y = master.winfo_height()/2,anchor = CENTER)
        label2.place(x=650,y = master.winfo_height()/2,anchor = CENTER)
        if not show_cam:
            Button(master, text = "Show the webcam", command = lambda : show(), font=("Abadi MT Condensed Extra Bold", 30), bg = 'snow').place(x=1200,y = master.winfo_height()/2,anchor = CENTER)
            Label(master, text ="This will return the video of your webcam (if you have a one).", font=("Abadi MT Condensed Extra Bold", 15), bg = 'medium aquamarine').place(x=1200,y = master.winfo_height()/2+55,anchor = CENTER)
            Label(master, text ="The same indicator as in the picture will show on the video", font=("Abadi MT Condensed Extra Bold", 15), bg = 'medium aquamarine').place(x=1200,y = master.winfo_height()/2+95,anchor = CENTER)
            Label(master, text ="to help you positioning your fingers.", font=("Abadi MT Condensed Extra Bold", 15), bg = 'medium aquamarine').place(x=1200+25,y = master.winfo_height()/2+135,anchor = CENTER)
            Label(master, text ="Opening the webcam can take a couple of seconds", font=("Abadi MT Condensed Extra Bold", 15), bg = 'medium aquamarine').place(x=1200+25,y = master.winfo_height()/2+175,anchor = CENTER)
   
    if val == 3:
        Label(master, text ="Fold your wrist until your hand forms a -45° angle", font=("Abadi MT Condensed Extra Bold", 30), bg = 'medium aquamarine').pack()
        Label(master, text ="with your arm as in the picture", font=("Abadi MT Condensed Extra Bold", 30), bg = 'medium aquamarine').pack()
        image1 = Image.open(os.path.join(path + os.sep,"image", "_45_wrist.png"))
        test1 = ImageTk.PhotoImage(image1)
        label1 = Label(image=test1, bg = 'medium aquamarine')
        label1.image = test1
        label1.place(x=400,y = master.winfo_height()/2,anchor = CENTER)
        if not show_cam:
            Button(master, text = "Show the webcam", command = lambda : show(), font=("Abadi MT Condensed Extra Bold", 30), bg = 'snow').place(x=1200,y = master.winfo_height()/2,anchor = CENTER)
            Label(master, text ="This will return the video of your webcam (if you have a one).", font=("Abadi MT Condensed Extra Bold", 15), bg = 'medium aquamarine').place(x=1200,y = master.winfo_height()/2+55,anchor = CENTER)
            Label(master, text ="The same indicator as in the picture will show on the video", font=("Abadi MT Condensed Extra Bold", 15), bg = 'medium aquamarine').place(x=1200,y = master.winfo_height()/2+95,anchor = CENTER)
            Label(master, text ="to help you positioning your fingers.", font=("Abadi MT Condensed Extra Bold", 15), bg = 'medium aquamarine').place(x=1200+25,y = master.winfo_height()/2+135,anchor = CENTER)
            Label(master, text ="Opening the webcam can take a couple of seconds", font=("Abadi MT Condensed Extra Bold", 15), bg = 'medium aquamarine').place(x=1200+25,y = master.winfo_height()/2+175,anchor = CENTER)
   
    if val == 4:
        Label(master, text ="Fold your wrist the other way until your hand", font=("Abadi MT Condensed Extra Bold", 30), bg = 'medium aquamarine').pack()
        Label(master, text ="forms a 45° angle with your arm as in the picture", font=("Abadi MT Condensed Extra Bold", 30), bg = 'medium aquamarine').pack()
        image1 = Image.open(os.path.join(path + os.sep,"image", "45_wrist.png"))
        test1 = ImageTk.PhotoImage(image1)
        label1 = Label(image=test1, bg = 'medium aquamarine')
        label1.image = test1
        label1.place(x=400,y = master.winfo_height()/2,anchor = CENTER)
        if not show_cam:
            Button(master, text = "Show the webcam", command = lambda : show(), font=("Abadi MT Condensed Extra Bold", 30), bg = 'snow').place(x=1200,y = master.winfo_height()/2,anchor = CENTER)
            Label(master, text ="This will return the video of your webcam (if you have a one).", font=("Abadi MT Condensed Extra Bold", 15), bg = 'medium aquamarine').place(x=1200,y = master.winfo_height()/2+55,anchor = CENTER)
            Label(master, text ="The same indicator as in the picture will show on the video", font=("Abadi MT Condensed Extra Bold", 15), bg = 'medium aquamarine').place(x=1200,y = master.winfo_height()/2+95,anchor = CENTER)
            Label(master, text ="to help you positioning your fingers.", font=("Abadi MT Condensed Extra Bold", 15), bg = 'medium aquamarine').place(x=1200+25,y = master.winfo_height()/2+135,anchor = CENTER)
            Label(master, text ="Opening the webcam can take a couple of seconds", font=("Abadi MT Condensed Extra Bold", 15), bg = 'medium aquamarine').place(x=1200+25,y = master.winfo_height()/2+175,anchor = CENTER)
   
    # We ask for a name
    if val == 5:
        if show_cam:
            cap.release()
            thread1.kill()
        Label(master, text="Enter your calibration name", font=("Abadi MT Condensed Extra Bold", 40), bg = 'medium aquamarine').pack(pady = 300)
        entry1 = Entry(master, font=("Abadi MT Condensed Extra Bold", 30), bg = 'medium aquamarine')
        entry1.place(x= master.winfo_width()/2, y = master.winfo_height()/2,anchor = CENTER)
        Button(master, text = "Submit!", command = lambda : getName(entry1.get()), font=("Abadi MT Condensed Extra Bold", 30), bg = 'snow').place(x= master.winfo_width()/2, y = master.winfo_height()/2+100,anchor = CENTER)
        
    if val<5:
        Button(master, text = "Done!", command = lambda : get_calibration(), font=("Abadi MT Condensed Extra Bold", 30), bg = 'snow').place(x=725, y=700)

# 3.1) Function that collects the data necessary to estimate the angle from the potentiometer values
def get_calibration():
    global angles_raw, val,coeff_MCP,coeff_PIP,coeff_wrist,wrist_val
    eraseWidget()
    if val==0:
        wrist_val[1] = angles_raw[18]
        for i in range(0,7):
            z_MCP[i] = angles_raw[i+10]
    if val < 3 :
        for j in range(0,5):
            x_PIP[j][val] = angles_raw[j]
            x_MCP[j][val] = angles_raw[j+5]
    
    if val == 3:
        wrist_val[0] = angles_raw[18]

    if val == 4:
        wrist_val[2] = angles_raw[18]

    val = val + 1
    if val == 5:
        for t in range(0,5):
            coeff_MCP[t] = np.polyfit(x_MCP[t],angle_calibration_MCP,2).tolist()
            coeff_PIP[t] = np.polyfit(x_PIP[t],angle_calibration_PIP,2).tolist()
        coeff_wrist = np.polyfit(wrist_val,angle_calibration_wrist,2).tolist()
    calibration() # it always goes back to the calibration function

# shows the webcam if activated
def show():
    global show_cam,cap
    show_cam = True
    cap = cv2.VideoCapture(0)
    cap.set(cv2.CAP_PROP_FRAME_WIDTH, 720)
    cap.set(cv2.CAP_PROP_FRAME_HEIGHT, 540)
    thread1.start()
    calibration()

#3.2) ONce the calibration is finished, the program needs to save the data in a JSON file
def getName(name):
    global coeff_MCP, coeff_PIP, z_MCP, coeff_wrist
    if os.path.isfile(os.path.join(path + os.sep, "sample.json")): # it verifies if a file already exists 
        with open(os.path.join(path + os.sep, "sample.json")) as json_open: # if there exists one, it opens it
            data = json.load(json_open)
            
        data['Usernames'].append({'name': name,'PIP': coeff_PIP,'MPCx': coeff_MCP,'MPCz': z_MCP,'wrist': coeff_wrist})

        with open(os.path.join(path + os.sep, "sample.json"),"w") as json_write:
            json.dump(data,json_write)

    else: # otherwise we create a file in the directory of the program
        data = {}
        data['Usernames'] = []
        data['Usernames'].append({'name': name,'PIP': coeff_PIP,'MPCx': coeff_MCP,'MPCz': z_MCP,'wrist': coeff_wrist})

        with open(os.path.join(path + os.sep, "sample.json"), "w") as json_create:
            json.dump(data, json_create)

    final_page() # Finally, the code arrives to the final page

# 4) It is called if the user choose to use a previous calibration
def NoCal():
    eraseWidget()
    Label(master, text ="Choose your calibration profile", font=("Abadi MT Condensed Extra Bold", 30), bg = 'medium aquamarine').pack(pady = 100)
    with open(os.path.join(path + os.sep, "sample.json")) as json_open:
        data = json.load(json_open)
    for user in data['Usernames'] : 
        Button(master, text = user['name'], command = lambda username = user: get_coeff(username['PIP'],username['MPCx'],username['MPCz'],username['wrist']), font=("Abadi MT Condensed Extra Bold", 30), bg = 'snow').pack(pady = 10)

# Function that replace the coefficient from the JSON
def get_coeff(PIP, MPCx, MPCz,wrist):
    global coeff_MCP, coeff_PIP, z_MCP, coeff_wrist
    coeff_PIP = PIP
    coeff_MCP = MPCx
    z_MCP = MPCz
    coeff_wrist = wrist
    final_page()

# 5) The final page just display a message (and decides if a connection to Unity occurs)
# A function can be added here with a thread to be used for anything
def final_page():
    Unity() #comment this line if you don't want a connection to Unity
    eraseWidget()
    Label(master, text ="You are ready to use the glove", font=("Abadi MT Condensed Extra Bold", 30), bg = 'medium aquamarine').pack(pady = 150)
    Label(master, text ="The angles are avaibles in the array 'angles'", font=("Abadi MT Condensed Extra Bold", 30), bg = 'medium aquamarine').pack(pady = 10)
    Label(master, text ="Or try in UNITY", font=("Abadi MT Condensed Extra Bold", 30), bg = 'medium aquamarine').pack()

# If called, it connects to the socket of Unity
def Unity():
    global unity,sock,s
    #Unity connection
    unity = True 
    host, port = "127.0.0.1", 25001# IP adress (should be same as client) and port number
    sock = socket.socket(socket.AF_INET, socket.SOCK_STREAM)
    sock.connect((host, port))
    # test part
    '''HOST,PORT = '192.168.43.49',65436  
    s = socket.socket(socket.AF_INET, socket.SOCK_STREAM)
    s.connect((HOST, PORT))
    '''

#----A class that allows a function/thread to be closed if it's an infinity loop---#
class thread_with_trace(Thread):
  def __init__(self, *args, **keywords):
    Thread.__init__(self, *args, **keywords)
    self.killed = False
  
  def start(self):
    self.__run_backup = self.run
    self.run = self.__run      
    Thread.start(self)
  
  def __run(self):
    sys.settrace(self.globaltrace)
    self.__run_backup()
    self.run = self.__run_backup
  
  def globaltrace(self, frame, event, arg):
    if event == 'call':
      return self.localtrace
    else:
      return None
  
  def localtrace(self, frame, event, arg):
    if self.killed:
      if event == 'line':
        raise SystemExit()
    return self.localtrace
  
  def kill(self):
    self.killed = True

#---------------function that treats, arranges and send the data----------------#
def read_function():
    global ready,angles_raw,angles,unity,sock,s
    while True:
        if ready == True:
            data = arduino.readline()[:-2]
            if data and len(data)==19:
                angles_raw = [float(x) for x in data.split()] 
                
                for i in range (0,5):
                    # PIP
                    angles[i] = poly_reg(coeff_PIP[i], angles_raw[i])
                    # MCPx
                    angles[i+5]= poly_reg(coeff_MCP[i], angles_raw[i+5])
                
                for i in range (0,7):
                    # MCPz
                    angles[i+10] = potToAngle(z_MCP[i])-potToAngle(angles_raw[i+10])
                
                #wirst values
                angles[17] = potToAngle(angles_raw[17])-180
                angles[18] = poly_reg(coeff_wrist, angles_raw[18])

                for i in range (0,4): 
                    # DIP
                    angles[i+19] = angles[i+1]*0.88
                    
                if unity:
                    #s.sendall(str(angles[7]).encode('utf-8'))
                    for i in range (0,23):
                        angles[i] = int(angles[i]*1000)
                    sock.sendall(json.dumps(angles).encode())
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

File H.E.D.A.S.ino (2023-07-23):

//Mux variables
int s0 = 7;
int s1 = 6;
int s2 = 5;
int s3 = 4;
int SIG_pin = A3;

const int sizeAngle = 19;
double angles[sizeAngle];

int muxChannel[16][4]={
  {0,0,0,0}, //channel 0
  {1,0,0,0}, //channel 1
  {0,1,0,0}, //channel 2
  {1,1,0,0}, //channel 3
  {0,0,1,0}, //channel 4
  {1,0,1,0}, //channel 5
  {0,1,1,0}, //channel 6
  {1,1,1,0}, //channel 7
  {0,0,0,1}, //channel 8
  {1,0,0,1}, //channel 9
  {0,1,0,1}, //channel 10
  {1,1,0,1}, //channel 11
  {0,0,1,1}, //channel 12
  {1,0,1,1}, //channel 13
  {0,1,1,1}, //channel 14
  {1,1,1,1}  //channel 15
};

void setup(){
  pinMode(s0, OUTPUT); 
  pinMode(s1, OUTPUT); 
  pinMode(s2, OUTPUT); 
  pinMode(s3, OUTPUT); 
  digitalWrite(s0, LOW);
  digitalWrite(s1, LOW);
  digitalWrite(s2, LOW);
  digitalWrite(s3, LOW);
  
  Serial.begin(115200);
    
}
 
void loop(){
 //-------Finger joints----------//
  for(int i = 0; i<4;i++){
      int channel = i*3+2;
      // PIP joints
      angles[i+1] = readMux(channel);
      // MCP x joints
      angles[i+6] = readMux(channel+1);
      // MCP z joints
      angles[i+11] = readMux(channel+2);
  }
  //thumb PIP/MPCx and MPCz
  angles[0] = analogRead(2);
  angles[5] = analogRead(4);
  angles[10] = analogRead(5);
  
  //thumb CMC x and y
  angles[15] = analogRead(6);
  angles[16] = analogRead(7);
  
  //wrist
  angles[17] = analogRead(0);
  angles[18] = analogRead(1);
  
  //-Printing on the serial monitor for Python to receive the data-//
  for(int i = 0; i < sizeAngle-1; i++)
  {
    Serial.print(angles[i]);Serial.print(" ");
  }
  Serial.println(angles[sizeAngle-1]);
 }

//functions
int readMux(int channel){
  int controlPin[] = {s0, s1, s2, s3};
  //loop through the 4 sig
  for(int i = 0; i < 4; i ++){
    digitalWrite(controlPin[i], muxChannel[channel][i]);
  }

  //read the value at the SIG pin
  int val = analogRead(SIG_pin);

  //return the value
  return val;
}

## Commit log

2021-07-13 arduino code
2021-07-24 calibration files renamed
2021-08-12 modification to 90° calibration
2021-08-12 stl files added
    [CE3_plaque.3mf, CMCz v3.f3z, accuracy test.stl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]
2022-01-11 Bill of materials
    [bill of materials.xlsx]
2023-03-23 Revert "Merge branch 'main' of https://github.com/ThAUJAS/H.E.D.A.S-Exoskeleton-glove-sensor-"
    This reverts commit 6429db331886fd3ce54a5e32cbe048d9d31a55fd, reversing
    changes made to 634528fd724867cb398e7c6b8243a0da211cabcd.
    [bill of materials.xlsx]
2023-03-25 Added condition to prevent wrong array size
    [HEDAS_code.py]
2023-07-16 Changing the pin that reads the multiplexer
2023-07-16 Re-uploading the right code
    [bill of materials.xlsx]
